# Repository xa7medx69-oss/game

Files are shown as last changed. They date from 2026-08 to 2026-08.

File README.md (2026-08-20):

# Physical Social Games

A reusable set of wearable ESP32-C3 game controls, a local hub, and a library of physical social games.

## Repository structure

| Folder | Contents |
|---|---|
| [`presentations/`](presentations/) | English and Arabic PowerPoint explainers |
| [`manuals/`](manuals/) | The 24 source manuals, compiled handbook, and expansion pack |
| [`hardware/`](hardware/) | PCB and enclosure design files |
| [`firmware/`](firmware/) | Wearable-node and hub firmware |
| [`software/`](software/) | Host web app, backend, and shared game logic |
| [`assets/`](assets/) | Images used by the manuals and presentations |
| [`tools/`](tools/) | Scripts that build, export, and verify project documents |

## Current status

The repository currently contains the complete product documentation, visual assets, compiled manuals, and game presentations. The PCB, enclosure, firmware, and host-application folders are ready for implementation files as development begins.

## Start here

1. Read the [product specification](manuals/chapters/01-product-specification.md).
2. Review the [hardware architecture](manuals/chapters/02-hardware-architecture.md) and [circuit design](manuals/chapters/03-circuit-design.md).
3. Use the [component list and BOM](manuals/chapters/04-component-list-and-bom.md) for the first prototype.
4. Follow the [firmware manual](manuals/chapters/06-firmware-manual.md) and [testing plan](manuals/chapters/14-testing-and-quality-plan.md).

See the [manual index](manuals/README.md) for the complete roadmap.

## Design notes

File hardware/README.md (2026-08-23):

# Hardware

Product hardware files belong here.

- [`pcb/`](pcb/) — schematics, PCB layouts, Gerbers, drill files, BOMs, and pick-and-place files.
- [`enclosure/`](enclosure/) — CAD, STL/STEP files, drawings, and assembly notes.
- [`3d-print/`](3d-print/) — print-ready prototype models, parametric generators, and build instructions.

The current design guidance is documented in manuals 02–05 and 12–15 under [`manuals/chapters`](../manuals/chapters/).

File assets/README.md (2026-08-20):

# Assets

- `games/` — illustrations and prompts for the 16-game PowerPoint decks.
- `handbook/` — diagrams and concept images used by the main handbook.
- `expansion-pack/` — illustrations for the eight-game expansion document.

Keep generated presentations and manuals out of this folder; their final files belong in `presentations/` and `manuals/compiled/`.

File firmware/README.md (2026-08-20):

# Firmware

ESP32-C3 product firmware belongs here.

Recommended layout:

- `wearable-node/` — button input, feedback, battery monitoring, and ESP-NOW communication.
- `hub/` — device pairing, event validation, game state, Wi-Fi, and WebSocket communication.
- `shared/` — shared packet definitions, IDs, constants, and tests.

Implementation requirements are in [Manual 06](../manuals/chapters/06-firmware-manual.md).

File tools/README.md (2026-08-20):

# Project Tools

- `presentations/` — builds the English and Arabic PowerPoint decks.
- `manuals/` — builds the Word manuals and exports PDFs.
- `quality/` — creates contact sheets for visual document review.

All scripts resolve paths from the repository root and no longer depend on a specific user's home directory.

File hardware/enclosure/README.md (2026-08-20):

# Enclosure Files

Place editable CAD files, printable STL files, STEP exports, drawings, and assembly notes here.

See [Manual 13](../../manuals/chapters/13-3d-printable-enclosure-instructions.md) for the current enclosure requirements.

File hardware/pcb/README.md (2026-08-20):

# PCB Files

Place the editable KiCad project here when circuit implementation begins.

Recommended layout:

- `wearable-node/` — wearable ESP32-C3 controller board.
- `hub/` — central ESP32-C3 hub board.
- `manufacturing/` — Gerbers, drill files, BOM, and pick-and-place exports.

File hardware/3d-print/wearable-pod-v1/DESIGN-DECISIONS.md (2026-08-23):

# Design Decisions

## Opening and closing method

The selected method is four metal M2 heat-set inserts in the base, four reusable screws through the lid, a radial tongue-and-groove alignment joint, and a separate TPU compression gasket.

| Method considered | Decision |
|---|---|
| Heat-set inserts and screws | Selected: repeatable servicing, controlled clamp force, replaceable gasket, and visible failure inspection |
| Screws directly into printed plastic | Rejected for regular servicing because threads wear and strip |
| Permanent snap fits | Rejected for the alpha because printer variation, fatigue, and hidden cracking make repeated battery access unreliable |
| Quarter-turn bayonet lid | Rejected for the wearable alpha because accidental rotation and uneven gasket compression require more physical validation |
| Adhesive or ultrasonic welding | Rejected because the battery and prototype electronics must remain serviceable |
| Magnets | Rejected because they do not provide controlled sealing force and are undesirable for a wearable attachment system |

## Button retention

The cap is installed from below the lid and has a larger underside flange. It therefore cannot leave the enclosure during play. Removing the four lid screws provides deliberate service access. A separate TPU diaphragm centers the press, limits dust entry, and transfers force to the switch.

## Attachment

The wearable interface is a separate screw-mounted plate rather than a clip molded into the electronics shell. Strap and clip experiments can therefore change without reprinting the sealed enclosure. The first build uses a wide fabric strap with a breakaway overlap; it avoids neck mounting and sharp metal against the body.

## Electronics layout

The battery and XIAO board sit side-by-side on a removable carrier. This avoids stacking the PCB directly over the pouch cell, improves inspection, and gives wires defined routes. The USB connector points toward the side opening. The external antenna must be routed separately after worn-position RF testing.

## Drop and sealing strategy

The TPU lower bumper is sacrificial and replaceable. The perimeter gasket and button diaphragm reduce dust/splash paths, but they do not create a certified ingress rating. A production seal needs material, compression, sweat, temperature-cycle, and laboratory ingress validation.

## Production path

This geometry is optimized for FDM prototype learning. After electronics, human-factors, and play testing stabilize, redesign it for injection molding with appropriate draft, ribs, uniform wall thickness, molded gasket features, and formal DFM review. Do not send this FDM model directly to tooling.

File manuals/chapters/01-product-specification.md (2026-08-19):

> Physical Social Games Business | Manual 01 | Version 0.1 | 2026-08-19

# Product Specification

## Purpose
Define the product to build, who it is for, what the MVP must prove, and what is deliberately postponed.

## Product promise
A reusable box of six wearable electronic controls and one hub that turns a room, garden, majlis, or event space into a library of original real-life games. The physical devices capture deliberate presses; the digital host controls rules, timing, teams, feedback, scoring, and replay.

**MVP decision:** build six wearable nodes plus one hub. The first release is a supervised prototype for adults and older teens, not a children's toy and not a finished waterproof consumer product.

## Flagship game: Pulse Hunt
**Objective:** survive until time expires, or as the Hunter eliminate all Runners.

**Players:** 4-6. One Hunter; 3-5 Runners. For three players, use one Hunter and two Runners with a shorter arena.

**Setup:** charge and assign one pod per player; clip pods high on the upper back; mark a clear play boundary; remove trip hazards; select 5-8 minutes; give Runners a 20-second head start; test every pod before starting.

**Core rules:** the Hunter eliminates a Runner by pressing the Runner's pod once until it confirms with light, vibration, and a sound from the host. Only the device may be touched. No grabbing, blocking doorways, tackling, pushing, hiding in locked rooms, stairs, roads, pools, kitchens, or vehicle areas. Eliminated players freeze, raise a hand, and walk to the safe zone.

**False-press protection:** a valid press is 80-900 ms, followed by a one-second lockout. The hub acknowledges the event. The node changes to red only after acknowledgement; if acknowledgement fails, it vibrates twice and retries.

**Winning:** Runners win if at least one remains alive at zero. The Hunter wins if all are eliminated. Tie-break: fastest complete elimination time.

**Variations:** two Hunters; team rescue with a 3-second teammate hold; three-life mode; shrinking arena announced by the host; silent mode using vibration only; score attack where each confirmed tag is one point and eliminated players re-enter after 20 seconds.

## Seven additional original games

| Game | Core idea | Button use |
|---|---|---|
| Vault Heist | Players steal digital gems while protecting their own vault. | Hold an opponent's pod for 1.5 seconds; a successful steal triggers a cooldown shield. |
| Signal Chain | Cooperative memory and movement challenge. | LEDs cue a changing player sequence; players press their own pods in order before time runs out. |
| Guardian Link | Secret pairs protect one another while completing public tasks. | A partner can cancel one hit by pressing the threatened player's pod within three seconds. |
| Territory Pulse | Teams control physical zones made from detached pods. | Hold a zone pod until its LED changes to the team's color; control scores over time. |
| Echo Match | Fast reaction and pattern recognition. | Players copy color/sound patterns on their own pods; fastest accurate response scores. |
| Silent Mission | Hidden individual objectives inside a normal gathering. | Short and long presses log secret actions; the host reveals completed missions at the end. |
| Relay Rush | Cooperative race against a dynamic route. | The host lights the next player's pod; correct presses pass the signal, mistakes add time. |

## Target user and occasion
Primary: UAE families and friend groups aged 14+, playing at villas, ghabgas, majlis-adjacent spaces, parks, and private gatherings. Secondary: birthdays, youth groups, hospitality venues, and later corporate events. The host should understand setup within three minutes and start a game within five.

## MVP acceptance criteria
- Six nodes connect through one hub without manual repair during a 30-minute session.
- A physical press appears in the UI within 200 ms at 95th percentile in the intended arena.
- At least 99.5% of deliberate valid presses are registered in a 1,000-press bench test.
- No duplicate scoring from one press; every event has a sequence number and acknowledgement.
- A new host can set up Pulse Hunt using only the quick-start page.
- In three playtests, at least 70% of participants request another round and rate fun at 4/5 or higher.

## Not in MVP
Native iOS/Android apps, cloud accounts, children under 14, public matchmaking, GPS, microphones, cameras, precise location tracking, custom injection-moulded tooling, certified waterproofing, and mass-production charging cases.

## Product risks and response
**Accidental activation:** use force/travel tuning, press windows, lockouts, hub acknowledgement, and playtesting. **Unsafe chasing:** strict arena rules, age gate, host briefing, and game modes that do not require running. **Wireless dropouts:** local star topology, retries, health beacons, and no cloud dependency. **One-game novelty:** ship only after three mechanics test well, then expand the library through software.

## Build instruction
Freeze this MVP specification for the first prototype sprint. New ideas go into a backlog unless they affect safety, event reliability, or the fun hypothesis.

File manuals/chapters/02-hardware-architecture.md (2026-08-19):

> Physical Social Games Business | Manual 02 | Version 0.1 | 2026-08-19

# Hardware Architecture

## Recommended MVP architecture
Use **six Seeed XIAO ESP32-C3 wearable nodes plus one XIAO ESP32-C3 hub**. Nodes send compact events to the hub over ESP-NOW. The hub runs a local Wi-Fi access point and WebSocket server; a phone or laptop joins the hub network and opens the local web interface. Internet is optional.

```text
[6 wearable nodes] -- ESP-NOW --> [hub] -- local Wi-Fi/WebSocket --> [phone/laptop browser]
```

This is better for the proof-of-concept than connecting six BLE peripherals directly to a phone: the host pairs once with the hub, the game works offline, event timing is centralized, and browser/device Bluetooth differences are removed. ESP32-C3 supports 2.4 GHz Wi-Fi and Bluetooth LE 5, so the same dev board preserves experimentation options. Official overview: https://docs.espressif.com/projects/esp-hardware-design-guidelines/en/latest/esp32c3/product-overview.html

## Node blocks
- XIAO ESP32-C3 module with antenna kept clear of battery and metal clip.
- Large momentary switch under a soft press cap.
- Addressable RGB LED or a 6-8 LED ring for player/status feedback.
- Coin vibration motor driven through a MOSFET.
- Optional piezo buzzer; keep node audio subtle and let the host produce most sound.
- 500 mAh protected LiPo, slide power switch, and USB-C charging through the board.
- Prototype enclosure with breakaway fabric strap or rounded clip.

## Hub blocks
- XIAO ESP32-C3 connected to USB power.
- ESP-NOW receiver and event authority.
- Local Wi-Fi access point, HTTP server, and WebSocket endpoint.
- USB serial debug channel; optional OLED only for diagnostics.

## Protocol
Each node sends `device_id`, `event_type`, `sequence`, `node_time_ms`, battery percentage, and a message authentication/check value. The hub deduplicates by device plus sequence, timestamps receipt, applies the game rule, and replies with an acknowledgement containing the accepted state. Retry at 40, 100, and 220 ms with random jitter, then show a local error pattern.

## Range target
Design for 25 m reliable line-of-sight and 10-15 m through typical villa partitions. Do not market a range until measured. Test the exact antenna orientation with the pod worn against different fabrics and body positions because the human body attenuates 2.4 GHz.

## Consumer architecture after validation
Re-evaluate a Nordic nRF52-class design for lower power and a robust proprietary 2.4 GHz/BLE hub. The nRF52840 supports Bluetooth LE, Bluetooth Mesh, NFC, Thread, and Zigbee, but it raises firmware/tooling and unit-cost complexity. Official product page: https://www.nordicsemi.com/products/nrf52840

## Battery and thermal targets
Active play: 8 hours minimum; shelf-off leakage: under 5% per month; charge time under 2.5 hours; protected cell; enclosure surface below 42 C in normal use. For the MVP, measure actual current in idle, active radio, LED animation, vibration, and power-off states before claiming runtime.

## Reliability rules
- The hub, not the node, owns the official game state.
- Never award points from an unacknowledged local press.
- Every node emits a health beacon every two seconds during a game.
- The UI warns at low battery, weak signal, or missed beacons.
- A reconnecting node requests current state before accepting gameplay input.

## Decision gate
Keep ESP-NOW through the first three playtest rounds. Change radio architecture only if measured packet loss, range, power, platform compatibility, or certification economics fail the targets.

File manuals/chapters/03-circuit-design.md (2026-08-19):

> Physical Social Games Business | Manual 03 | Version 0.1 | 2026-08-19

# Circuit Design

## Prototype node wiring

| Function | XIAO ESP32-C3 pin | Circuit instruction |
|---|---|---|
| Main press | D1 / GPIO3 | Switch to GND; enable internal pull-up; add 100 nF only if software debounce is insufficient. |
| RGB LED | D2 / GPIO4 | WS2812 data through 330 ohm series resistor; 100 uF across LED supply; limit brightness in firmware. |
| Buzzer | D3 / GPIO5 | Drive piezo or magnetic buzzer through an NPN transistor and base resistor; add flyback protection if inductive. |
| Vibration | D4 / GPIO6 | Logic-level N-MOSFET low-side drive; flyback diode across coin motor; 100 nF motor suppression. |
| Battery sense | D0 / GPIO2 | 220 k/100 k divider to ADC; enable through a transistor if idle leakage matters. |
| Power | BAT and GND | Protected 3.7 V LiPo to battery pads; physical slide switch in series for a true off state. |

## Electrical rules
Keep the 2.4 GHz antenna edge free of copper, battery, motor, steel clip, and fingers. Place motor and buzzer away from the antenna. Add test pads for 3V3, GND, button, LED data, UART TX/RX, and battery. Use keyed battery connectors and strain relief. Do not charge unattended during early prototypes.

## Switch and press design
The large visible cap should transfer force to a small rated tactile switch without side-loading it. Start with 1.5-2.5 N actuation and 0.5-1.0 mm perceived travel. The enclosure must prevent clothing pressure from maintaining the switch. A raised protective rim helps but must not make intentional presses difficult.

## Protection for a production PCB
Include reverse-polarity protection, LiPo over-charge/over-discharge/short protection, USB ESD protection, motor transient suppression, programming pads, a reset method, and a current-measurement link. Use only a certified battery pack and document cell traceability.

## Verification instruction
Before connecting a battery, perform continuity and resistance checks. Power from a current-limited bench supply at 3.8 V with a 150 mA limit, confirm quiescent current, then test each output separately. Record peak current during LED white, motor start, radio transmit, and combined worst case.

## Production handoff outputs
Schematic PDF, ERC-clean source, PCB layout, Gerbers, drill files, pick-and-place, BOM with manufacturer part numbers and alternates, test-point map, programming fixture drawing, and a written bring-up procedure.

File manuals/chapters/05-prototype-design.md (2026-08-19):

> Physical Social Games Business | Manual 05 | Version 0.1 | 2026-08-19

# Prototype Design

## Prototype stages
**P0 - one-button proof:** one node, one hub, one browser. Demonstrate press, acknowledgement, UI state, and reconnect.

**P1 - six wired-on-bench nodes:** six powered nodes on a table. Run 1,000 scripted/manual presses, duplicates, simultaneous events, resets, and low-signal tests.

**P2 - wearable alpha:** battery power, 3D-printed housings, straps/clips, LED and vibration. Conduct controlled walking-speed games.

**P3 - playtest kit:** refined enclosures, labelled IDs, carry tray, charging checklist, host guide, and three complete game modes.

## Enclosure target
Prototype diameter 58-65 mm; depth 20-28 mm; mass below 70 g; 45-50 mm press area; minimum 2 mm rounded shell walls; no sharp external corners; recessed power switch; USB-C access that cannot be hit during play. Use a replaceable fabric/clip interface so the electronics do not need redesign when wear testing changes.

## Attachment
Start with a wide hook-and-loop armband/back strap plus a rounded clip adapter. Avoid strong magnets near medical devices and avoid lanyards or neck mounting. A production attachment should release under abnormal load and must not use a sharp metal edge against the body.

## Build order
1. Flash unique IDs and radio keys onto all boards.
2. Assemble hub and verify all six nodes on USB power.
3. Add one battery-powered node and measure current/temperature.
4. Clone the validated wiring to the other five.
5. Print one enclosure, conduct fit/press/antenna checks, then print the set.
6. Run bench reliability before any active play.
7. Run a safety briefing and low-speed playtest before chase variants.

## Exit criteria
Six nodes run 30 minutes without a reset, every node reconnects within five seconds after power cycling, the host sees battery/signal status, and two unfamiliar hosts can set up using the quick-start instructions.

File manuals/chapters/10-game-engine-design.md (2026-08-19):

> Physical Social Games Business | Manual 10 | Version 0.1 | 2026-08-19

# Game Engine Design

## Principle
Hardware emits simple physical facts; game definitions decide meaning. A `PRESS` must not be hard-coded as elimination because the same input may steal points, capture a zone, confirm a sequence, rescue a teammate, or complete a mission.

## Engine components
Game manifest; configuration schema; player/team allocator; deterministic reducer; timers; random seed service; rule validators; effect dispatcher; score/winner evaluator; pause/recovery; replay log.

## Normalized inputs
`PRESS`, `HOLD_STARTED`, `HOLD_COMPLETED`, `RELEASE`, `DEVICE_ONLINE`, `DEVICE_OFFLINE`, `BATTERY_LOW`, and host commands. The engine accepts only validated inputs from known devices in the current session.

## Game definition contract
Each game declares player range, age guidance, space and activity level, setup, allowed roles, defaults, event handlers, state shape, feedback effects, winner conditions, timeouts, reconnection policy, safety warning, and analytics events.

## Determinism
Store the random seed at session creation. Timers are derived from the hub monotonic clock. Every state change emits an immutable domain event. This makes bugs reproducible and supports match replay without video or personal tracking.

## New-game checklist
Write a one-sentence fun promise; define player choices; identify the physical action; cap downtime; add a comeback path; specify ambiguous simultaneous events; define disconnection behavior; run a paper prototype; then implement. Reject games whose novelty depends only on changing colors or scores.

## Portfolio balance
Launch library target: one chase game, one team strategy game, one cooperative memory game, one low-mobility social/hidden-mission game, and one reaction game. This makes the kit useful across villas, indoor gatherings, mixed mobility, and short/long sessions.

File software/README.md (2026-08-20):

# Software

Host-side product code belongs here.

Recommended layout:

- `web-app/` — local browser interface served by the hub.
- `game-engine/` — reusable game rules and state machines.
- `backend/` — optional online services added after the offline MVP.
- `shared/` — schemas, types, and shared utilities.

See manuals 07–11 under [`manuals/chapters`](../manuals/chapters/).

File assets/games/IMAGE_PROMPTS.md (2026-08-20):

# Image prompt set

Mode: OpenAI built-in image generator.

Hardware/style reference: `assets/handbook/kit-concept.png`.

## Shared direction

Each game used the following shared production direction, combined with its scene brief below:

```text
Use case: illustration-story
Asset type: 16:9 PowerPoint game explainer illustration
Audience: understandable at a glance by a 10-year-old
Input image: the kit concept is a hardware and palette reference for round electronic pods; preserve navy shells and teal, coral, amber, and warm-white lights
Style/medium: polished friendly 3D children's educational illustration, rounded forms, expressive poses, clean modern composition
Color palette: deep navy, teal, coral, amber, warm off-white
Constraints: no written words, no numbers, no logos, no watermark; show safe device use; avoid grabbing, pushing, tackling, dangerous obstacles, or threatening behavior
```

## Selected scene briefs

1. **Pulse Hunt** — Bright garden with a glowing safe boundary. Exactly five players: one Hunter presses only a Runner's upper-back pod, two Runners move safely, and one tagged player raises a hand and walks to a teal safe zone.
2. **Vault Heist** — Two glowing team vault circles. A player safely holds an opponent's arm pod, a gem-shaped light moves between vaults, and a shield ring appears after the steal.
3. **Signal Chain** — Six players in a semicircle. Their pods light in a visible sequence connected by arrows; the first player presses their own pod while the others remember the next turn.
4. **Guardian Link** — Secret pairs are suggested by matching heart-light links. A partner presses the threatened player's pod in time, creating a protective shield that cancels a hit.
5. **Territory Pulse** — Three safe floor zones with detached pods on stable bases. Two teams walk between zones while teal and coral lights show which team controls each area.
6. **Echo Match** — Six players around a central hub that shows a simple three-color pattern. Players copy the pattern on their own pods; a star glow marks the first correct answer.
7. **Silent Mission** — Six players at a friendly gathering, each with one harmless mission symbol in a thought bubble. A central player quietly presses their own wrist pod; a table hub shows completed stars.
8. **Relay Rush** — Six players arranged along a curved route. A glowing signal travels through arrows from one lit pod to the next; a clock icon shows that mistakes add time.
9. **Crown Circuit** — Three-beat visual story: an amber crown marks the holder, a challenger presses the Crown pod, then the two duelists press their own pods after a flash while other pods lock.
10. **Courier Code** — Exactly five seated players. A glowing envelope moves during a secret handoff, the Interceptor safely scans a different pod and gets a miss, and another player performs a decoy.
11. **Double Lock** — Stable table pods and a visual color clue. Two players hold the matching pods simultaneously as progress bars meet and a large lock opens.
12. **Market Rush** — Six seated players trade fictional Spark, Fabric, and Time icons. Two players confirm together, resources swap, and a completed icon-only contract creates a Reputation star.
13. **Power Grid** — Six pods form a generator ring around a glowing miniature city. Players raise output, cool a hot pod, and link two pods for a repair while supply and demand bars match.
14. **Rhythm Rivals** — Six players follow colored beat waves from a central hub. Pods glow before each cue; two players hit a shared team note and earn a perfect-timing star.
15. **Switchback** — Six seated players form a circle. A white Signal sits on the active pod while arrows show short, long, and double-press routes; a reverse icon flips the directions.
16. **Ghost Frequency** — Six players conduct a pair test. The hub returns a green same-result, an icon-only evidence graph connects colored dots, and the hidden Drifter has a small playful static swirl.

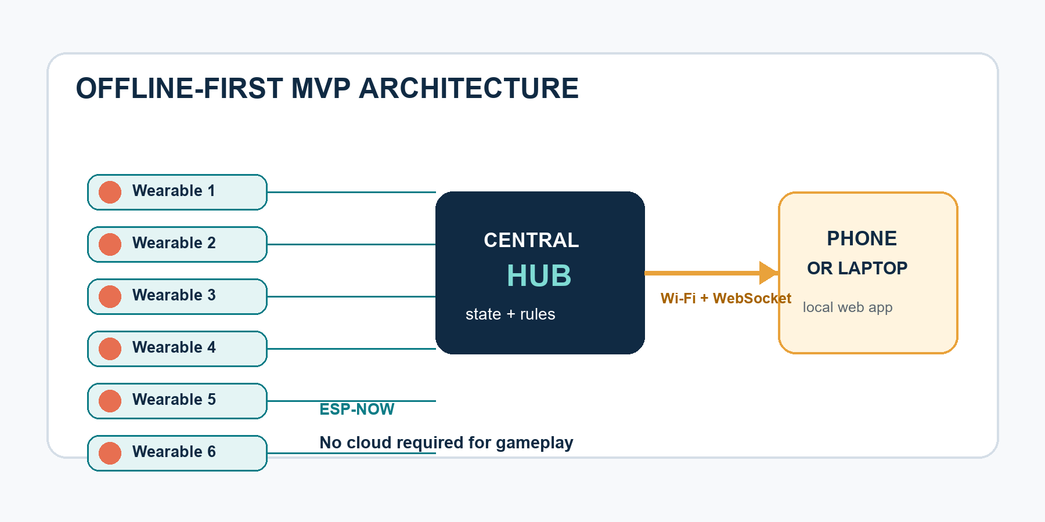
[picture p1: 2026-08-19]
assets/handbook/architecture.png

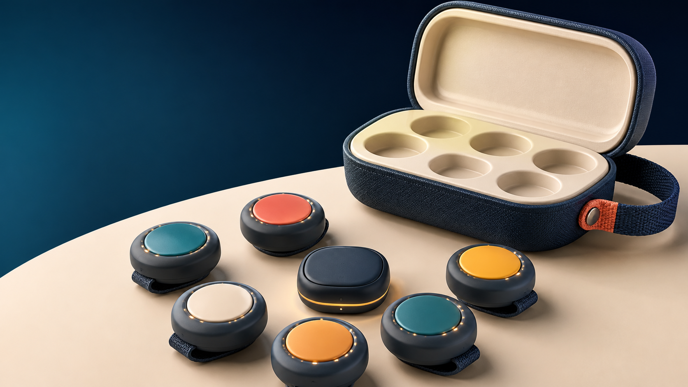
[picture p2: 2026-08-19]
assets/handbook/kit-concept.png

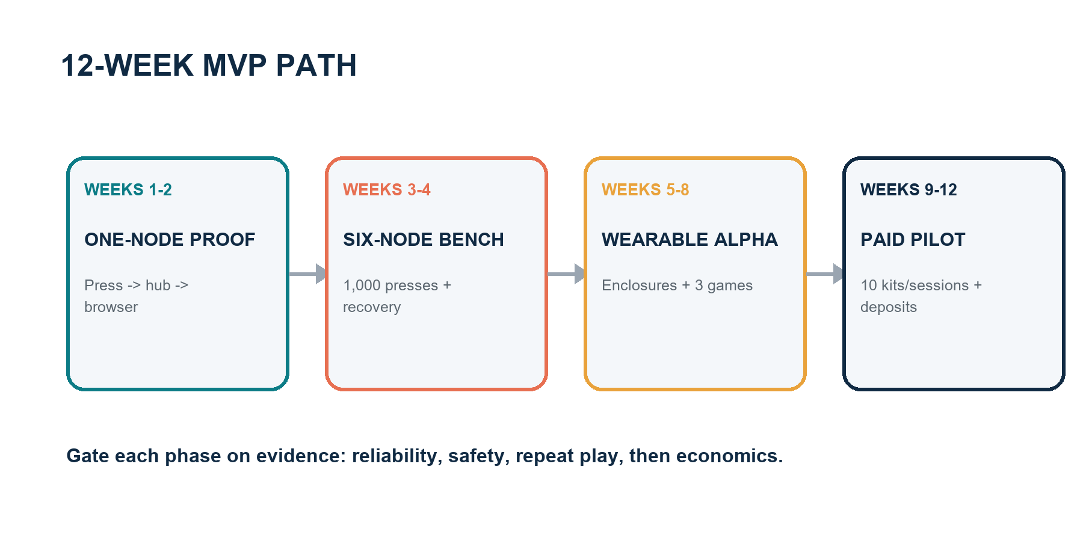
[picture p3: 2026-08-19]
assets/handbook/roadmap.png

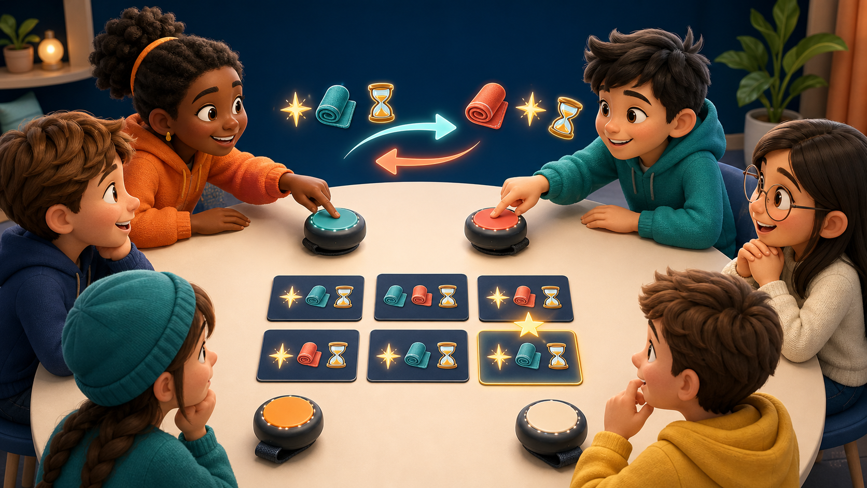
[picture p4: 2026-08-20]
assets/games/12-market-rush.png

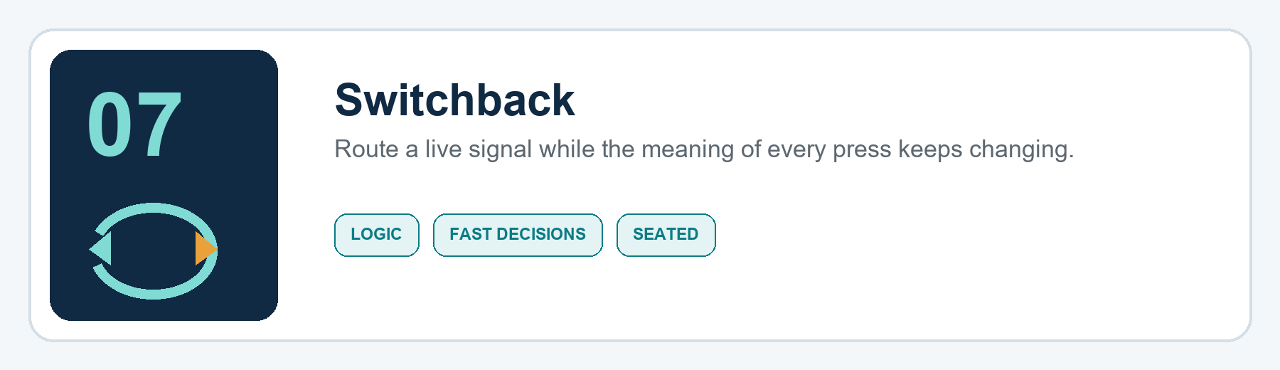
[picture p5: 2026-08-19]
assets/expansion-pack/game-07.png

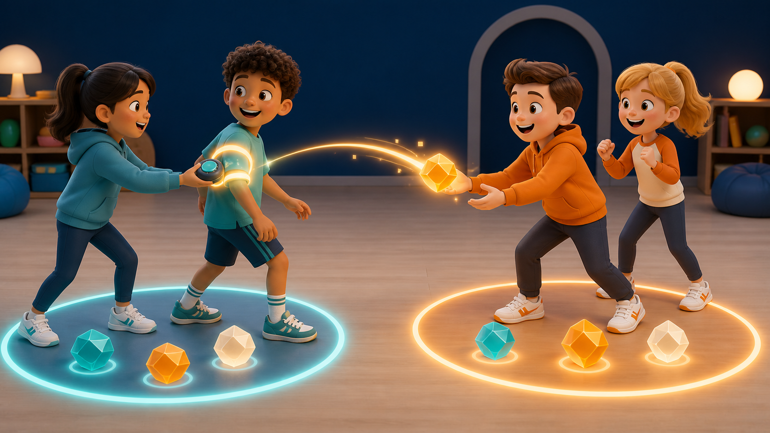
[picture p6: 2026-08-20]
assets/games/02-vault-heist.png

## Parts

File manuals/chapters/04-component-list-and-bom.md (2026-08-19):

> Physical Social Games Business | Manual 04 | Version 0.1 | 2026-08-19

# Component List and BOM

## Buy list for one seven-board MVP

| Item | Qty | Planning cost (AED) | Notes |
|---|---:|---:|---|
| Seeed XIAO ESP32-C3 | 7 | 210-315 | Six nodes plus one hub; buy one spare if budget allows. |
| Protected 500 mAh LiPo | 6 | 90-150 | Use reputable packs with correct polarity and connectors. |
| Large momentary switches/caps | 8 | 35-80 | Six plus spares; prototype arcade or low-profile caps. |
| RGB LEDs/rings | 8 | 40-90 | One per node plus spares. |
| Coin vibration motors | 8 | 40-80 | Optional in prototype round one but recommended. |
| Buzzers, MOSFETs, diodes, passives | 1 lot | 35-70 | Breadboard/protoboard stage. |
| Power switches and wire/connectors | 1 lot | 30-60 | Add strain relief and insulation. |
| USB-C charging cable set/charger | 1 | 45-90 | Multi-port quality charger; never use damaged cells. |
| Prototype enclosures/straps/clips | 6 | 90-180 | 3D printing, hook-and-loop, fabric straps. |
| Hub case and optional OLED | 1 | 35-75 | OLED is diagnostic, not required. |

**Expected prototype total:** approximately AED 615-1,190 before tools, shipping, and failed parts. This is a planning range, not a supplier quote.

## Required tools
Temperature-controlled soldering iron, lead-free or appropriately handled solder, flux, flush cutters, wire stripper, heat-shrink, multimeter, USB power meter, bench supply with current limit, small scale/calipers, and access to a 3D printer. A basic logic analyser is useful for debugging.

## Supplier discipline
Record supplier, order date, exact MPN, lot/batch, price, lead time, datasheet URL, and substitute. Do not silently swap batteries, radios, switches, or plastics. For each critical part maintain one approved alternate and document the validation needed after substitution.

## Cost-down ladder
Prototype dev boards first; then one custom PCB; then panelized PCBs and a simple machined/printed enclosure; only after demand validation consider injection moulding and a charging case. Do not spend on tooling before event reliability and repeat-play are proven.

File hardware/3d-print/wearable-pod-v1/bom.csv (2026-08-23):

category | item | quantity | material_or_specification | notes
printed | Base shell | 1 | PETG | Contains inserts and electronics
printed | Top lid | 1 | PETG | Four-screw service closure
printed | Button cap | 1 | PETG | 47.4 mm press face
printed | Button membrane | 1 | TPU 95A | Flip after printing so plunger points down
printed | Perimeter gasket | 1 | TPU 95A | Replace if permanently compressed or damaged
printed | Light ring | 1 | Natural or translucent PETG | Optical performance requires LED testing
printed | Drop bumper | 1 | TPU 95A | Stretch-on replaceable impact part
printed | Strap mount | 1 | PETG | Two 29 x 5 mm strap slots
printed | Electronics carrier | 1 | PETG | Measure battery before use
fastener | M2 button-head screw | 4 | M2 x 6 mm | Hand tighten in cross pattern
fastener | M2 heat-set insert | 4 | Approx. 3.2 mm OD x 3 mm | Select pilot using coupon
fastener | M2.5 low-profile screw | 2 | M2.5 x 6 mm | Strap plate attachment
fastener | M2.5 heat-set insert | 2 | Approx. 3.7 mm OD | Blind underside bosses
fastener | M2 thread-forming screw | 2 | Length selected after physical stack measurement | Electronics carrier
soft_good | Wearable strap | 1 | 25 mm soft hook-and-loop | Breakaway overlap required
soft_good | Battery retaining strap | 1 | 8 mm fabric or hook-and-loop | No rigid clamp across pouch cell
soft_good | Wearer pad | 1 | Thin closed-cell foam | Replaceable and cleanable
electronics | Controller board | 1 | Seeed XIAO ESP32-C3 21 x 17.8 mm | Verify assembled height and antenna lead
electronics | Battery | 1 | Protected LiPo maximum modeled envelope 31 x 21.5 x 6.5 mm | Exact qualified pack required
electronics | Tactile switch and actuator | 1 | 1.5-2.5 N target | Physical height controls button travel

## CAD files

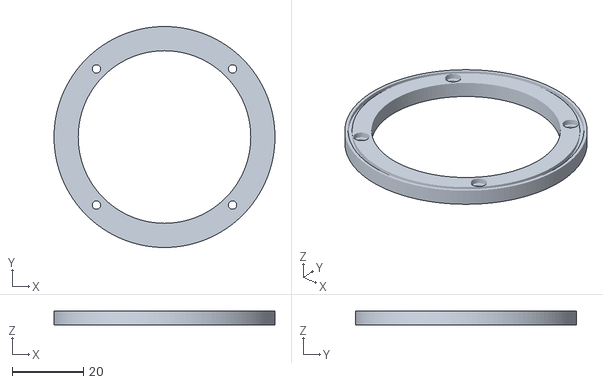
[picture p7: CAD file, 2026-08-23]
hardware/3d-print/wearable-pod-v1/stl/02-top-lid.stl
62.0 x 62.0 x 4.00

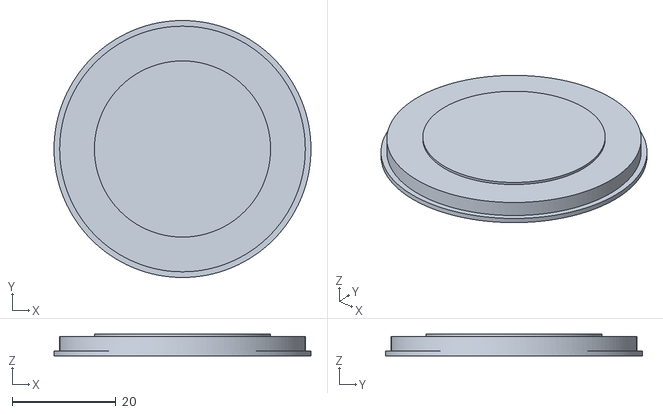
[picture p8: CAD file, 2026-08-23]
hardware/3d-print/wearable-pod-v1/stl/03-button-cap.stl
49.6 x 49.6 x 4.15

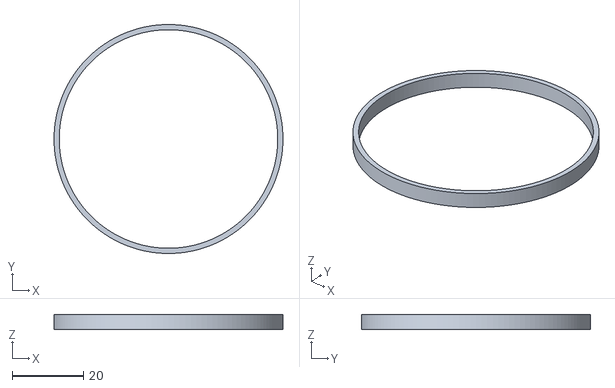
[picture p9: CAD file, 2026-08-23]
hardware/3d-print/wearable-pod-v1/stl/07-drop-bumper-tpu.stl
64.4 x 64.4 x 4.20

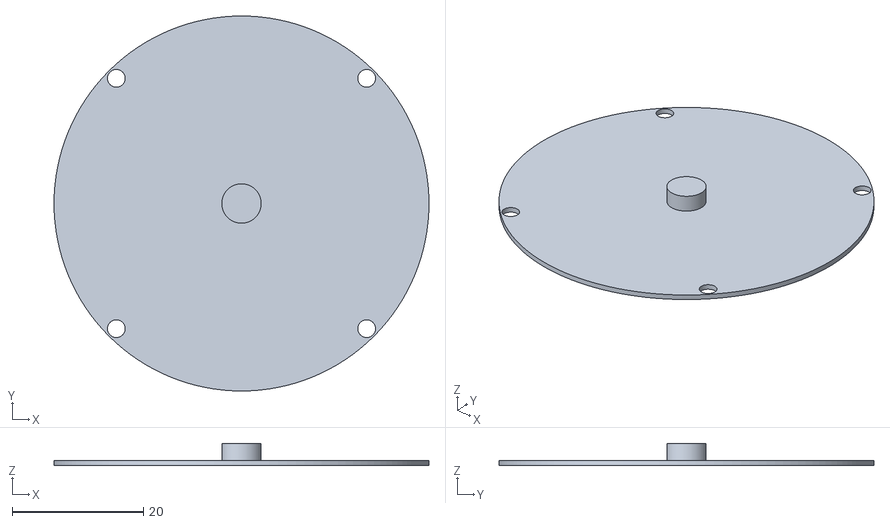
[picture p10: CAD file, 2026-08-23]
hardware/3d-print/wearable-pod-v1/stl/04-button-membrane-tpu.stl
57.2 x 57.2 x 3.40

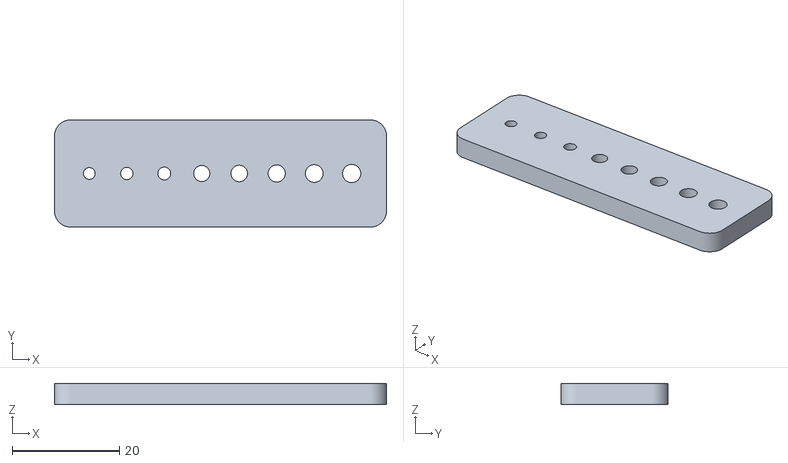
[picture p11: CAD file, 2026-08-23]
hardware/3d-print/wearable-pod-v1/stl/10-tolerance-coupon.stl
62.0 x 20.0 x 4.00

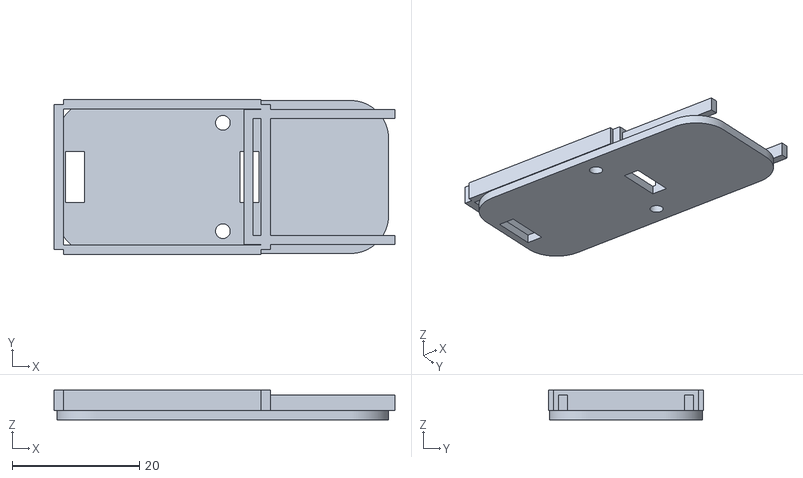
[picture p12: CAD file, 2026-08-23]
hardware/3d-print/wearable-pod-v1/stl/09-electronics-carrier.stl
53.5 x 24.3 x 4.70

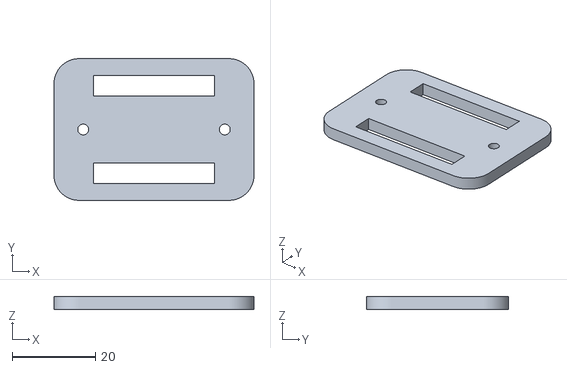
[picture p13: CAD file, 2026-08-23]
hardware/3d-print/wearable-pod-v1/stl/08-strap-mount.stl
48.0 x 34.0 x 3.00

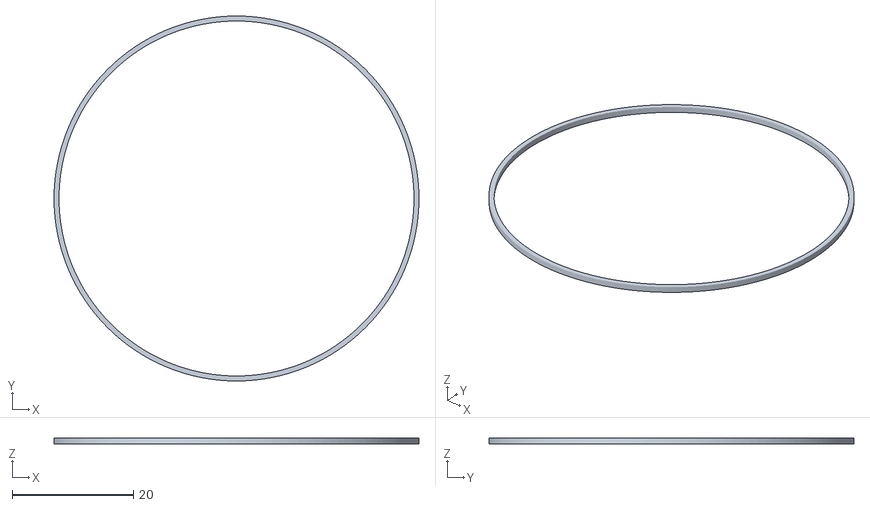
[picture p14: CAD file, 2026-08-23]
hardware/3d-print/wearable-pod-v1/stl/06-light-ring-transparent.stl
60.2 x 60.2 x 1.00

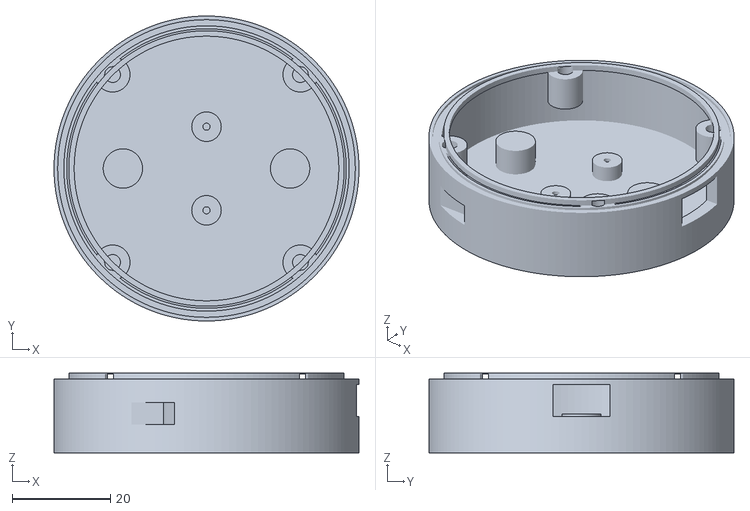
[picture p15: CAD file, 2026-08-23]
hardware/3d-print/wearable-pod-v1/stl/01-base-shell.stl
62.0 x 62.0 x 16.2

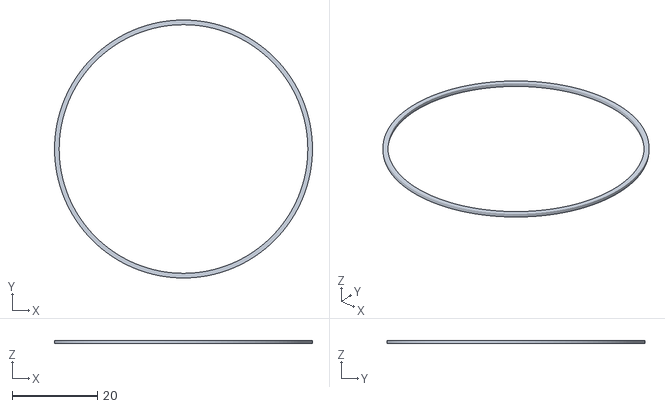
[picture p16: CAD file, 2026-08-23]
hardware/3d-print/wearable-pod-v1/stl/05-perimeter-gasket-tpu.stl
60.4 x 60.4 x 0.8

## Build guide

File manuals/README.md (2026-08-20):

# Physical Social Games Business - Manual Index

A practical, original, UAE-ready roadmap from playable prototype to launch

## Files

01. [Product Specification](chapters/01-product-specification.md)
02. [Hardware Architecture](chapters/02-hardware-architecture.md)
03. [Circuit Design](chapters/03-circuit-design.md)
04. [Component List and BOM](chapters/04-component-list-and-bom.md)
05. [Prototype Design](chapters/05-prototype-design.md)
06. [Firmware Manual](chapters/06-firmware-manual.md)
07. [Website and Host App](chapters/07-website-and-host-app.md)
08. [Backend and API](chapters/08-backend-and-api.md)
09. [Database and Data Model](chapters/09-database-and-data-model.md)
10. [Game Engine Design](chapters/10-game-engine-design.md)
11. [UI and UX Manual](chapters/11-ui-and-ux-manual.md)
12. [Industrial Design Manual](chapters/12-industrial-design-manual.md)
13. [3D-Printable Enclosure Instructions](chapters/13-3d-printable-enclosure-instructions.md)
14. [Testing and Quality Plan](chapters/14-testing-and-quality-plan.md)
15. [Manufacturing Plan](chapters/15-manufacturing-plan.md)
16. [Packaging and Quick-Start](chapters/16-packaging-and-quick-start.md)
17. [Branding Manual](chapters/17-branding-manual.md)
18. [Pricing Manual](chapters/18-pricing-manual.md)
19. [Business Model Manual](chapters/19-business-model-manual.md)
20. [Marketing Manual](chapters/20-marketing-manual.md)
21. [Launch Strategy](chapters/21-launch-strategy.md)
22. [UAE Business and Compliance](chapters/22-uae-business-and-compliance.md)
23. [Legal and IP Manual](chapters/23-legal-and-ip-manual.md)
24. [Future Expansion Roadmap](chapters/24-future-expansion-roadmap.md)

## Compiled files

- [Business handbook (PDF)](compiled/Physical-Social-Games-Business-Handbook.pdf)
- [Business handbook (Word)](compiled/Physical-Social-Games-Business-Handbook.docx)
- [Separate manuals archive](compiled/Physical-Social-Games-Separate-Manuals.zip)
- [Eight-game expansion pack](expansion-pack/README.md)

## Start here

Read Manual 01, buy from Manual 04, follow Manual 05, implement Manual 06, and use Manual 14 before active playtests.

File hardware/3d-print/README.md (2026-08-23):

# 3D-Printable Hardware

## Current model

- [`wearable-pod-v1/`](wearable-pod-v1/) — serviceable 62 mm wearable game-button enclosure.

Every model folder should contain editable parametric source, print-ready STL files, a BOM, print settings, assembly instructions, validation notes, and a revision history.

These are prototype files. A successful slice or print does not prove electrical, battery, impact, skin-contact, ingress, or child-product safety.

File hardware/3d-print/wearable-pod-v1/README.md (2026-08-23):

# Wearable Pod V1

A serviceable, parametric enclosure for one wearable Physical Social Games button.

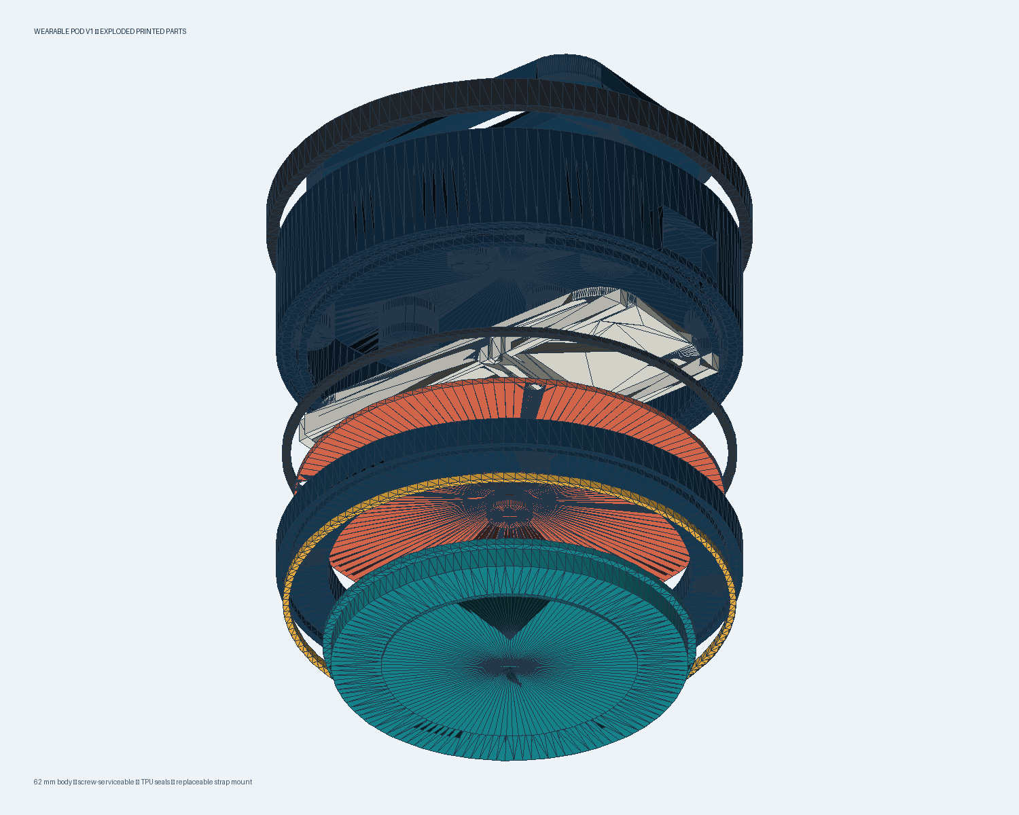
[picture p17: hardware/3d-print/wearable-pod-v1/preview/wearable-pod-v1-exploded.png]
Exploded enclosure preview


## Design summary

- 62 mm nominal body diameter.
- 47.4 mm obvious press surface with approximately 0.8 mm intended travel.
- Four M2 screws into heat-set inserts for repeatable opening and closing.
- Tongue-and-groove shell alignment plus a replaceable TPU compression gasket.
- Captured button cap: it cannot fall out while the enclosure is closed.
- Separate TPU diaphragm for dust resistance and compliant button return.
- Removable electronics carrier for a 21 × 17.8 mm XIAO ESP32-C3 and a battery up to 31 × 21.5 × 6.5 mm.
- Separate USB-C and recessed power-switch openings.
- Replaceable two-screw strap plate with two 29 × 5 mm strap slots.
- Stretch-on TPU drop bumper.
- No glue is required to service the enclosure.

## Files

- [`generate_models.py`](generate_models.py) — editable parametric source.
- [`model-validation.json`](model-validation.json) — recorded mesh and mechanical-clearance checks.
- [`stl/`](stl/) — ten generated and watertight print files.
- [`preview/wearable-pod-v1-exploded.glb`](preview/wearable-pod-v1-exploded.glb) — interactive exploded 3D model.
- [`preview/critical-dimensions.svg`](preview/critical-dimensions.svg) — first-build dimensional reference.
- [`PRINTING.md`](PRINTING.md) — material, orientation, slicing, and tolerance guidance.
- [`ASSEMBLY.md`](ASSEMBLY.md) — complete opening, closing, and assembly process.
- [`DESIGN-DECISIONS.md`](DESIGN-DECISIONS.md) — why this closure and attachment method were selected.
- [`bom.csv`](bom.csv) — printed and purchased parts.

## Important assumptions

The official XIAO ESP32-C3 board outline is 21 × 17.8 mm, but connected wires, the external antenna, battery connector, and solder joints also need clearance. The battery envelope in this model is only a starting maximum. Measure the exact purchased cell and all assembled electronics with calipers before printing six housings.

The enclosure is not certified waterproof and must not be described with an IP rating. The gasket and diaphragm are prototype dust/splash-control features that require physical testing.

Critical dimensions

## Regenerating the files

```powershell
python -m pip install -r requirements.txt
python generate_models.py
```

The generator rejects parts that are not watertight, have inconsistent triangle winding, or have non-positive volume.

## References

- [Official Seeed Studio XIAO ESP32-C3 dimensions and resources](https://wiki.seeedstudio.com/XIAO_ESP32C3_Getting_Started/)
- [Project enclosure requirements](../../../manuals/chapters/13-3d-printable-enclosure-instructions.md)
- [Project industrial-design requirements](../../../manuals/chapters/12-industrial-design-manual.md)

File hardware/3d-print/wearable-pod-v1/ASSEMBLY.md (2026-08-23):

# Assembly, Opening, and Closing

## Purchased hardware

- Four M2 × 6 mm button-head screws for the top lid.
- Four M2 heat-set inserts, approximately 3.2 mm outside diameter and 3 mm long, selected using the tolerance coupon.
- Two M2.5 × 6 mm low-profile screws for the strap plate.
- Two matching M2.5 heat-set inserts, approximately 3.7 mm outside diameter.
- Two M2 thread-forming screws for the removable electronics carrier.
- 25 mm wide soft hook-and-loop strap with a breakaway overlap.
- 8 mm removable battery-retaining strap.
- Thin closed-cell foam wearer pad and battery insulation.

Do not substitute fasteners until their head, length, thread engagement, and internal clearance have been checked in CAD and in a transparent or empty test assembly.

## Heat-set inserts

1. Print and test the tolerance coupon.
2. Support the boss from below on a flat surface.
3. Use a temperature-controlled insertion tip sized for the insert.
4. Press vertically without forcing or twisting the boss.
5. Stop when the insert is flush; do not push it into the battery cavity.
6. Let the plastic cool fully before inserting a screw.
7. Reject a boss that is cracked, distorted, loose, or visibly tilted.

Install four M2 inserts from the open top of the base. Install the two strap-mount inserts from the wearer-facing underside.

## Electronics carrier

1. Measure the finished battery. It must fit without bending, pinching, or compressing the pouch cell.
2. Add electrical insulation between the cell and every PCB/solder surface.
3. Place the battery in the left pocket and retain it with an 8 mm removable fabric strap through the two carrier slots. Do not use a rigid clamp across the cell.
4. Slide the XIAO board into the right-side rails with USB-C toward the side opening.
5. Route the external antenna away from the battery, vibration motor, metal screws, and the wearer’s body. Do not coil the antenna lead tightly.
6. Route wires with service loops and strain relief. No wire may cross a screw boss, shell tongue, gasket, button plunger, or sharp printed edge.
7. Attach the carrier using two M2 thread-forming screws. Tighten by hand only.

## Button and lid stack

1. Place the translucent light ring into the lid’s upper annular recess.
2. Insert the rigid button cap from the underside of the lid. Its larger flange must remain below the lid opening.
3. Flip the TPU membrane from its print orientation so its plunger points down toward the tactile switch.
4. Place the membrane under the cap and align its four screw holes.
5. Confirm that the cap moves freely approximately 0.8 mm and returns without rubbing.
6. Adjust the physical switch/actuator height with a designed spacer—not loose tape—if the switch is not actuated consistently across the full cap.

## Closing the enclosure

1. Power the pod off and disconnect USB.
2. Confirm the battery is secure and undamaged.
3. Inspect the tongue, groove, gasket recess, wire routes, and screw bosses for debris.
4. Lay the TPU perimeter gasket flat in the base recess. Do not stretch or twist it.
5. Lower the completed lid vertically so the tongue enters the groove. Never trap a wire under the sealing surface.
6. Insert all four M2 screws and turn each one only two rotations.
7. Tighten gradually in a diagonal cross pattern until the gap is uniform and the gasket is lightly compressed.
8. Do not use a powered screwdriver and do not crush the printed lid.
9. Press the cap at its center and around four edges. It must return every time.
10. Run button, LED, vibration, radio, charging, and power-switch tests before fitting the strap.

## Opening the enclosure

1. End the game, power the pod off, unplug USB, and wait for all LEDs to turn off.
2. Remove the strap plate if it blocks safe handling.
3. Loosen the four lid screws gradually in a diagonal pattern.
4. Lift the lid vertically using equal finger pressure around the rim.
5. Do not insert a metal screwdriver near the battery. If the gasket sticks, use a broad plastic opening pick only at the external shell seam.
6. Keep screws, gasket, cap, membrane, and light ring together in a clean parts tray.
7. Inspect the cell before touching or moving internal wiring. Stop if it is swollen, hot, leaking, punctured, or smells unusual.

## Attachment and safety

Pass a soft 25 mm strap through both slots in the removable plate. The strap should release under abnormal load; do not use a neck lanyard, permanent zip tie, rigid metal band, or strong magnet. Add a replaceable foam pad between the plate and clothing/body. The two attachment screws must end inside their blind bosses and must never protrude into the electronics cavity.

## Validation before active play

- 100 manual presses at the center and four edges.
- 30-minute powered test while worn.
- USB insertion/removal without shell movement.
- Ten open/close service cycles with no loose inserts or boss cracks.
- One-metre controlled drop testing onto wood and carpet with an inert battery substitute first.
- Strap pull/release test using a documented fixture, not a person’s neck or limb.
- Radio-range test in the actual worn orientation.

This prototype is not approved for unsupervised children or commercial sale.

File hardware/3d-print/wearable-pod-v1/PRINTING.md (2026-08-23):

# Printing Instructions

## Print one tolerance coupon first

Print `10-tolerance-coupon.stl` using the same material, nozzle, layer height, and wall settings planned for the housing.

The eight holes from left to right are:

`2.2, 2.3, 2.4, 3.0, 3.1, 3.2, 3.3, 3.4 mm`

Use the first three to select an M2 clearance hole. Use the last five to select the heat-set-insert pilot hole. Change the constants near the top of `generate_models.py` if your printer needs compensation.

## Materials

| Part | Recommended prototype material | Reason |
|---|---|---|
| Base, lid, cap, strap mount, carrier | PETG | Tough, printable, and suitable for functional mechanical parts |
| Button membrane, gasket, bumper | TPU 95A | Flexible, replaceable, and impact absorbing |
| Light ring | Natural/translucent PETG | Diffuses LEDs better than an opaque shell |

PETG is appropriate for prototypes, but do not leave the pod in a closed vehicle in UAE heat. For higher-temperature testing, evaluate ASA or a suitable PC blend using an enclosed printer. Production material selection requires impact, chemical, sweat, UV, flammability, and regulatory review.

## Baseline slicer settings

- 0.4 mm nozzle.
- 0.20 mm layer height; 0.16 mm for the membrane and gasket if available.
- Four perimeters for rigid structural parts.
- Five top and bottom layers.
- 30–40% gyroid or adaptive-cubic infill.
- 100% infill for the gasket and membrane.
- Elephant-foot compensation enabled after measuring the coupon.
- Seam positioned away from USB, switch, gasket, and button-guide surfaces.
- No automatic scaling.

## Orientation

| STL | Build-plate orientation |
|---|---|
| `01-base-shell` | Flat wearer-facing bottom on the plate; cavity upward |
| `02-top-lid` | Flat underside on the plate |
| `03-button-cap` | Retaining flange on the plate; visible face upward |
| `04-button-membrane-tpu` | Flat diaphragm on the plate; plunger upward; flip during assembly |
| `05-perimeter-gasket-tpu` | Flat |
| `06-light-ring-transparent` | Flat |
| `07-drop-bumper-tpu` | Flat |
| `08-strap-mount` | Flat wearer-facing side on the plate |
| `09-electronics-carrier` | Large base plate on the plate |
| `10-tolerance-coupon` | Flat |

The parts are designed to avoid mandatory support. If a printer struggles with the carrier rails, use support from the build plate only and keep support away from board-contact surfaces.

## Acceptance inspection

Reject and reprint a part if it has layer separation, a warped gasket surface, a cracked boss, sharp strings inside the battery compartment, blocked USB/switch access, a cap that rubs or remains depressed, or strap-slot damage.

PETG guidance: [Prusa PETG material documentation](https://help.prusa3d.com/article/petg_2059).

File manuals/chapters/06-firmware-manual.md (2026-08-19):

> Physical Social Games Business | Manual 06 | Version 0.1 | 2026-08-19

# Firmware Manual

## Node firmware modules
Board support; unique identity; input/debounce; event queue; ESP-NOW transport; acknowledgements/retry; LED/haptic patterns; battery monitor; health beacon; configuration storage; diagnostics; signed update placeholder.

## Node state machine
`BOOT -> SELF_TEST -> PAIRING/READY -> ACTIVE -> ELIMINATED/LOCKED -> READY -> LOW_BATTERY -> SHUTDOWN`.

A press is accepted only in ACTIVE, within the configured duration, after debounce, and outside lockout. The node immediately shows a neutral "pending" flash, sends the event, and only shows success after the hub acknowledges it.

## Event packet
```c
struct PressEvent {
  uint8_t version;
  uint8_t device_id;
  uint8_t event_type;
  uint8_t flags;
  uint32_t sequence;
  uint32_t uptime_ms;
  uint16_t battery_mv;
  uint16_t auth_tag;
};
```

## Timing targets
Debounce 25 ms; valid press 80-900 ms; hold event at configurable 1,500 or 3,000 ms; local input lockout 1,000 ms; health beacon 2 s; event acknowledgement target under 120 ms; reconnect target under 5 s.

## Hub firmware
Maintain allow-listed node MACs/IDs, receive and deduplicate packets, translate to normalized game events, persist the last state snapshot, serve local web assets, broadcast WebSocket updates, log diagnostics, and send effect/state commands back to nodes.

## Security baseline
Use per-kit keys, allow-listed devices, a random kit Wi-Fi password, no open debug endpoints in a sale unit, no default cloud credential, monotonic sequence handling, and signed firmware updates before commercial launch. Security is a release requirement even when gameplay data seems harmless.

## Development workflow
Use PlatformIO or ESP-IDF with a reproducible lockfile/toolchain. Keep node and hub projects in one repository with shared packet definitions and tests. Every release gets a semantic version, build hash, protocol version, and migration note.

## Firmware test instruction
Unit-test debounce and state transitions; fuzz malformed packets; simulate duplicate/out-of-order packets; power-cycle during game; run 1,000 presses per node; measure latency distribution; test weak signal; test a dead node; and verify that a stale packet cannot re-eliminate or re-score.

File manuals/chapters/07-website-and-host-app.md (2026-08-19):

> Physical Social Games Business | Manual 07 | Version 0.1 | 2026-08-19

# Website and Host App

## MVP surface
A responsive local web app served by the hub. The host joins the kit Wi-Fi, opens the local address/QR code, creates players, assigns node IDs, selects a game, performs a device check, and starts.

## Required screens
Welcome/connect; create session; player names; button assignment; game library; rule configuration; preflight device check; live game dashboard; pause/abort; winner/results; diagnostics; export log.

## Live dashboard
Show game title and round, timer, player cards, alive/eliminated or score state, team colors, connection and battery warnings, recent event feed, pause, and emergency end. The host must never need to scroll to reach pause/end on a phone.

## Interaction rules
Use large touch targets, high contrast, color plus icon/text status, visible confirmation for destructive actions, and an offline indicator. Do not rely on sound alone. Avoid mandatory accounts or phone numbers for the prototype.

## QR joining
For the MVP, QR opens the host page on the local hub network; players do not need individual phones. Later, optional spectators can join a read-only screen. Do not expose control URLs without session authorization.

## Suggested stack
TypeScript, Vite, React or lightweight vanilla components, CSS variables/design tokens, and WebSocket transport. Build to static assets embedded in the hub filesystem. Use a shared JSON schema for normalized game events.

## Acceptance tests
360 px phone width; latest Chrome/Edge/Safari UI rendering; no internet; reconnect after the phone locks; large player names; six simultaneous events; timer drift; low battery warning; pause/resume; and safe recovery after hub refresh.

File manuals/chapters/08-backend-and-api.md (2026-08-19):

> Physical Social Games Business | Manual 08 | Version 0.1 | 2026-08-19

# Backend and API

## MVP decision
Keep the authoritative backend on the local hub. Cloud is not required to play. This prevents venue internet from becoming a gameplay dependency and keeps the privacy footprint small.

## Local endpoints
- `GET /api/kit` - identity, firmware, protocol, battery summary.
- `POST /api/session` - create a new game session.
- `POST /api/session/{id}/players` - assign player and device.
- `POST /api/session/{id}/start|pause|resume|end` - controlled transitions.
- `GET /api/session/{id}` - current snapshot.
- `WS /ws/session/{id}` - real-time events and state patches.
- `GET /api/diagnostics/export` - support log without personal history by default.

## Event flow
Hardware events are normalized before the game engine sees them. The engine produces domain events such as `PLAYER_ELIMINATED`, `POINT_STOLEN`, or `SEQUENCE_ADVANCED`. The state reducer is deterministic; replaying the same ordered domain events must produce the same state.

## Cloud phase
Add optional accounts, game catalogue updates, telemetry consent, customer support, purchases, and cross-device history only after the local game is stable. Use regional/legal review for hosting and transfers, encrypt in transit and at rest, and collect the minimum necessary data.

## Operational requirements
Structured logs with timestamps and correlation IDs; no secrets in logs; rate limiting; schema validation; idempotency keys for commands; explicit API versioning; device and app compatibility matrix; safe rollback for updates.

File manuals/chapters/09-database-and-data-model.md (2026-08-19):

> Physical Social Games Business | Manual 09 | Version 0.1 | 2026-08-19

# Database and Data Model

## Local model
Use a small embedded store or append-only JSON event log on the hub. Core records: Kit, Device, Player, Session, Team, GameDefinition, GameConfig, RawHardwareEvent, DomainEvent, StateSnapshot, Result, FirmwareVersion.

## Minimal fields
`Device(id, hardware_rev, firmware, battery, last_seen, signal)`; `Session(id, game_id, created_at, started_at, ended_at, status, config_version)`; `Player(id, display_name, device_id, team_id)`; `Event(id, session_id, sequence, source, type, payload, received_at)`.

## Data rules
Display names can be temporary nicknames; delete session names after a configurable period; do not collect birth dates, exact location, contacts, photos, audio, or biometrics. Separate operational telemetry from gameplay history and use explicit consent for cloud analytics.

## Retention default
Raw radio diagnostics: seven days on support builds, disabled or bounded in production. Local session history: last 20 sessions unless the host clears it. Cloud customer profile: only while the account is active plus a documented legal/operational retention period.

## Migration and backup
Version every schema and game definition. Apply forward migrations with a backup/snapshot. If migration fails, preserve the previous playable version and show a clear support code.

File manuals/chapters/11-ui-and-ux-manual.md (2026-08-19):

> Physical Social Games Business | Manual 11 | Version 0.1 | 2026-08-19

# UI and UX Manual

## Experience target
Open box to first round in under five minutes. The host should answer only: who is playing, which pod belongs to whom, which game, and any optional rule.

## Setup flow
1. Power hub and six pods.
2. Scan QR or join the kit network.
3. Watch six device tiles turn ready.
4. Tap a physical pod; the matching tile animates; enter player name.
5. Choose a game and accept the safety briefing.
6. Run a three-second feedback test and start.

## Status language
Use plain words: Ready, Weak signal, Low battery, Paused, Eliminated, Reconnecting. Pair colors with icons and text. Red means unavailable/eliminated, amber means attention, teal means active/ready, and blue means neutral/system.

## Failure recovery
If a pod drops, pause automatically only when the current game cannot continue fairly. Show which pod failed and a one-tap `Replace device` flow. Preserve the timer and state. Never make the host rebuild all player assignments.

## Accessibility
Minimum 4.5:1 contrast for normal text, 44 px touch targets, scalable type, no meaning by color alone, optional reduced motion, captions/text equivalents for sound, and haptic alternatives. Include low-mobility games and a no-running filter in the library.

## Research script
Observe without coaching: unbox, charge, assign, choose, start, recover one disconnected pod, and explain a result. Record completion time, errors, questions, and confidence. Improve the flow before adding more decoration.

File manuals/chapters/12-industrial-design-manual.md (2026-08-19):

> Physical Social Games Business | Manual 12 | Version 0.1 | 2026-08-19

# Industrial Design Manual

## Design intent
Premium, friendly, obvious to press, comfortable on clothing, and durable enough for repeated gatherings. It should look like a social-game object, not a medical alarm, security tracker, or television-show prop.

## Geometry targets
Consumer goal 55-60 mm diameter, 18-23 mm body depth, under 55 g, 42-48 mm press surface, 1.5-2.5 N activation, rounded R2+ edges, recessed power switch, protected USB-C or contact charging, and a replaceable attachment module.

## CMF direction
Deep navy main shell, soft teal active surface, coral/amber state accents, warm off-white case interior. Matte fine texture hides scratches; glossy light pipe only where needed. Avoid excessive neon and avoid six unrelated toy colors.

## Feedback hierarchy
Host screen carries complex information. Pod feedback stays glanceable: color/state, one short vibration, and rare local sound. Do not expose raw connection codes during normal play.

## Durability goals
Prototype: 1 m drop to wood/carpet, 5,000 presses. Engineering validation: repeated 1.2 m multi-face drops, 100,000 press cycles, sweat/skin-oil wipe tests, 0-45 C operating evaluation, transport vibration, and ingress tests appropriate to the final claim. Never print an IP rating without certified testing.

## Human-factors tests
Different fabrics, abayas/jackets/T-shirts, standing/sitting, left/right hand, reduced grip, accidental leaning, and quick device removal. Test antenna performance while worn, not only on a bench.

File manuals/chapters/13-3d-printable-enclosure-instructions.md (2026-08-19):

> Physical Social Games Business | Manual 13 | Version 0.1 | 2026-08-19

# 3D-Printable Enclosure Instructions

## Parametric starting dimensions
Outer diameter 62 mm; total depth 25 mm; wall 2.0 mm; top-cap travel 0.8 mm; press disk 48 mm; LED light-pipe groove 2.5 mm; PCB standoffs sized to the selected dev board; battery pocket with 0.6-1.0 mm clearance; four M2 heat-set inserts or snap features; clip rail on the back.

## Print recommendation
Print housing in PETG for tougher functional parts; TPU 95A for the press membrane/bumper; 0.2 mm layers; four perimeters; 30-40% infill; orient the back shell flat and the press cap face-up. Keep support away from snap and gasket surfaces.

## Assembly sequence
Deburr; fit heat-set inserts; install switch actuator; place light pipe; mount PCB; route motor and battery without crossing antenna keep-out; secure battery with removable foam tape; add insulation; close shell; fit clip/strap; verify press around the full cap; perform radio and charge tests.

## Safety rules
No exposed screw tips, conductive edges, pinched battery, loose cell, sharp clip, strong neck attachment, or inaccessible power isolation. Reject any printed part with cracks, warped battery pocket, or a cap that can jam down.

## CAD deliverables
Native parametric file, STEP, STL/3MF per part, drawing with critical dimensions/tolerances, exploded assembly, BOM, print orientation sheet, revision table, and a change log tied to playtest findings.

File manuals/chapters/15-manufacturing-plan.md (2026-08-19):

> Physical Social Games Business | Manual 15 | Version 0.1 | 2026-08-19

# Manufacturing Plan

## Phases
EVT validates electronics and radio; DVT validates mechanical design, safety, reliability, and pre-compliance; PVT validates tooling, assembly process, fixtures, yield, packaging, and traceability; mass production begins only after signed exit reports.

## Supplier package
Gerbers, drawings, tolerances, golden sample, approved vendor list, controlled BOM, firmware image/hash, programming/test procedure, cosmetic standards, packaging spec, serial/lot format, change-control process, and defect criteria.

## End-of-line test
Program identity/keys; verify current draw; main press; LED colors; vibration/buzzer; radio packet/ack; RSSI at fixture distance; battery voltage; charge detection; firmware/version; label scan; final visual inspection. Store pass/fail by serial and lot.

## Yield targets
Pilot first-pass yield >=90%; production target >=97% after process stabilization. Any supplier substitution requires documented equivalence and targeted revalidation, especially battery, radio module, antenna materials, switch, plastics, and charger.

## UAE market gates
Wireless telecommunications equipment intended for UAE sale requires TDRA review/type approval under the applicable regime; current service requirements can include technical data sheets and accredited radio/EMF/safety reports. Confirm classification before production: https://tdra.gov.ae/en/Services/service-card?sID=Cu4EDmeifjoQ1zAbgYV59qYlswfGAtcsK_IwGX8c0LQ

Products subject to UAE technical regulations may require a MoIAT conformity certificate and accredited test report: https://moiat.gov.ae/en/services/issue-conformity-certificates-for-regulated-products

Do not print conformity marks, IP ratings, age claims, or certifications until formally earned and documented.

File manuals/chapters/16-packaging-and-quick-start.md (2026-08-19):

> Physical Social Games Business | Manual 16 | Version 0.1 | 2026-08-19

# Packaging and Quick-Start

## Box contents
Six numbered wearable pods, one hub, six attachment straps/clips, one charging solution, USB cable, quick-start card, safety card, game library card/QR, warranty/support information, and inventory checklist.

## Opening experience
The lid shows three steps: power, join, play. Devices sit in numbered wells. Status LEDs are visible during charging. The host should not need to remove a lower tray before learning setup.

## Quick-start copy
1. Charge all pods and power the hub.
2. Place pods high on the upper back using the provided attachment.
3. Scan the hub QR and join the kit network.
4. Tap each pod to assign a player.
5. Choose a game, clear the play area, review the safety rules, and start.

## Safety card
Use only in a clear private play area. No pushing, grabbing, tackling, road/pool/stair play, or device placement on neck/face. Touch only the wearable device. Stop for pain, overheating, damaged battery, cracked housing, or unsafe behavior. MVP use is supervised and 14+.

## Sustainability
Right-size the box, minimize mixed plastics, make paper separable, use replaceable straps, design devices for battery/service access by trained technicians, and avoid a permanently decorative insert that prevents efficient shipping.

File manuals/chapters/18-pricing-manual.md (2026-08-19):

> Physical Social Games Business | Manual 18 | Version 0.1 | 2026-08-19

# Pricing Manual

## Pricing method
Price from landed cost and customer value, not only competitor markup. Landed cost includes product, hub, battery, accessories, packaging, freight, customs, certification amortization, payment fees, warranty reserve, returns, fulfilment, support, and VAT treatment.

## Working model
If mature landed COGS is AED 220-320, a direct-to-consumer price hypothesis of AED 699-999 gives room for payment, fulfilment, warranty, marketing, and channel discounts. Do not publish this range until willingness-to-pay and supplier quotes are tested.

## Validation
Test three concept prices with the same offer; collect purchase intent and deposits, not compliments; compare family-use vs event-use positioning; test whether included games, carry/charging case, and bilingual content increase value; record refund/objection reasons.

## Margin guardrails
Target DTC gross margin before marketing of 55-65% once scaled. Wholesale requires sufficient margin for the retailer and your support/warranty burden. Hardware subscriptions should not be necessary for basic play.

## Offer ladder
Core six-player kit; accessory straps/replacement pods; larger group expansion; paid premium game packs only after a strong free library; event/corporate bundle with facilitation tools; rental for trial and hospitality.

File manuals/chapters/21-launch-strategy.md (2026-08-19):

> Physical Social Games Business | Manual 21 | Version 0.1 | 2026-08-19

# Launch Strategy

## Stage 1 - proof (weeks 1-4)
One-node technical proof, six-node bench test, Pulse Hunt paper prototype, and ten customer interviews. Gate: reliable events and clear demand for active social play.

## Stage 2 - alpha (weeks 5-8)
Wearable housings, local host UI, Pulse Hunt plus Signal Chain and Echo Match, five supervised groups. Gate: repeat play, safe behavior, setup under five minutes.

## Stage 3 - paid pilot (weeks 9-12)
Ten kits or facilitated sessions, deposits/fees, support logs, willingness-to-pay, and supplier DFM review. Gate: no open critical defects and credible unit economics.

## Stage 4 - engineering validation
Custom PCB, DVT enclosure, battery/charger validation, pre-compliance testing, TDRA/MoIAT classification, privacy/legal documents, brand clearance, and pilot manufacturer.

## Stage 5 - controlled UAE launch
Limited inventory, local fulfilment, bilingual quick-start/safety material, responsive support, spare stock, and weekly defect/review meeting. Expand only after return, support, and reliability metrics stabilize.

## Stop conditions
Unsafe common behavior, persistent missed/duplicate hits, less than 50% desire to replay after iteration, setup consistently above ten minutes, supplier cost that destroys contribution margin, or regulatory path inconsistent with the model.

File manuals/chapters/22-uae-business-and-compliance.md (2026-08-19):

> Physical Social Games Business | Manual 22 | Version 0.1 | 2026-08-19

# UAE Business and Compliance

## Business setup
Select the exact activities first: e-commerce/trading of electronic games or toys, software/content, import, and possibly event services. Mainland setup steps include activity, legal form, trade licence, trade name, initial approval, premises, and additional approvals: https://u.ae/en/information-and-services/business/doing-business-on-the-mainland/steps-to-start-a-business-on-the-mainland

A free-zone company may face regulated access to mainland sales, so model the intended sales channel and distributor structure before choosing. Obtain professional UAE legal/accounting advice for the specific emirate and activities.

## Wireless and product conformity
Confirm TDRA equipment classification and supplier registration/type-approval requirements before commercial import or sale. Current policy covers entities involved in registration, approval, import, distribution, display, sale, and commercial use of telecommunications equipment. Start here: https://tdra.gov.ae/en/Services/service-card?sID=Cu4EDmeifjoQ1zAbgYV59qYlswfGAtcsK_IwGX8c0LQ

Confirm whether the kit, battery charger, and toy/electronic classification are regulated under MoIAT conformity programmes. A conformity application for regulated products requires a valid trade licence and accredited test report: https://moiat.gov.ae/en/services/issue-conformity-certificates-for-regulated-products

## Data protection
UAE Federal Decree-Law No. 45 of 2021 creates obligations for personal-data processing, security, consent/other lawful bases, rights, and cross-border transfers. Minimize data and keep MVP play local: https://u.ae/en/about-the-uae/digital-uae/data/data-protection-laws.

## Tax
As of this handbook date, UAE resident businesses must register for VAT when taxable supplies/imports exceed AED 375,000 in the prior 12 months or are expected to exceed it in the next 30 days; voluntary threshold is AED 187,500. Verify current rules and your facts: https://www.tax.gov.ae/en/services/vat.registration.aspx

## Practical compliance file
Trade licence/activities; customs/importer setup; TDRA correspondence and certificate; MoIAT classification/certificate; battery transport documents including UN 38.3; accredited safety/EMC/radio reports; supplier declarations; labels/manuals; risk assessment; privacy notice/terms; warranty/returns; incident/recall plan; serial/lot traceability.

## Important limitation
This manual is a planning checklist, not legal, tax, safety-certification, or regulatory advice. Confirm requirements with the relevant UAE authorities and qualified advisors before sale, import, claims, or children's use.

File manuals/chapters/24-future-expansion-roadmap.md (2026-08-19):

> Physical Social Games Business | Manual 24 | Version 0.1 | 2026-08-19

# Future Expansion Roadmap

## Phase A - prove the platform
Six nodes, one hub, three excellent games, offline host UI, adult/older-teen supervised use, reliable event protocol, and repeat-play evidence.

## Phase B - consumer kit
Custom low-power PCB, certified battery/charging, robust enclosure and attachment, manufactured case, five-game library, bilingual content, updates, diagnostics, and UAE compliance.

## Phase C - library and accessories
Expansion pods to 8/12 players, floor/territory bases, wrist/vest attachments, spectator mode, seasonal game packs, creator tools with rule validation, and accessibility filters.

## Phase D - events and corporate
Multi-kit orchestration, facilitator dashboard, team analytics that avoid intrusive employee profiling, rental fleet management, quick sanitation/service, venue mode, and certified facilitators.

## Phase E - regional/global
Arabic/English localization quality, country-specific radio/product approvals, distributor/service strategy, regional cloud/data review, climate testing, and localized game research.

## Technology options to revisit
Lower-power Nordic radio architecture; charging contacts/case; secure OTA; larger mesh/multi-hub events; UWB only if precise ranging creates a proven game mechanic; motion sensors only after button simplicity is exhausted. Avoid feature creep that weakens reliability or setup.

## North-star metrics
Median setup under five minutes; session success >99%; repeat play within 30 days; games played per kit; support contacts per 100 sessions; return rate; contribution margin; safety incidents; and percentage of active owners using more than one game.

## Next seven actions
Buy the seven-board BOM; build the one-node proof; run a paper Pulse Hunt; implement acknowledged events; assemble six bench nodes; conduct the 1,000-press test; schedule the first supervised playtest and record the scorecard.

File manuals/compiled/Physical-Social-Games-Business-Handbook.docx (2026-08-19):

BUILD MANUAL • VERSION 0.1

Physical Social Games Business

A practical, original, UAE-ready roadmap from playable prototype to launch

Concept render of six wearable game buttons, one hub, and an open carry case

Original concept visualization: six wearable controls plus one hub and carry case.

Prepared as an execution handbook • UAE focus • 19 August 2026

# Executive decision

Build seven devices, not six: six wearable ESP32-C3 nodes and one central hub. Use ESP-NOW node-to-hub and a local Wi-Fi web app. Prove reliability and fun offline before custom electronics, apps, cloud, tooling, or certification spend.

## How to use this handbook

- Read Manual 01 to freeze scope.
- Buy from Manual 04 and build in the order in Manual 05.
- Use Manuals 06-11 for firmware/software implementation.
- Do not run active playtests until Manual 14's bench and safety gates pass.
- Use Manuals 15 and 22-23 before commercial import, claims, or sale.

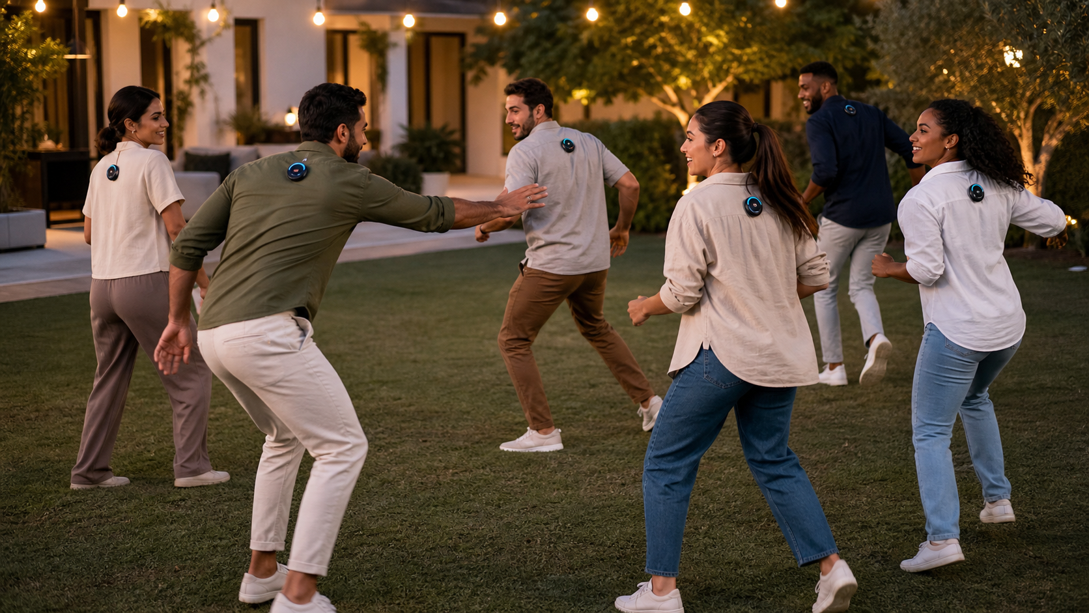
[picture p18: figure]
Six adults safely playing a wearable-button game in a cleared villa garden

Intended experience: social, premium, active, and safe in a cleared private play area.

## Manual index

No. | Manual
01 | Product Specification
02 | Hardware Architecture
03 | Circuit Design
04 | Component List and BOM
05 | Prototype Design
06 | Firmware Manual
07 | Website and Host App
08 | Backend and API
09 | Database and Data Model
10 | Game Engine Design
11 | UI and UX Manual
12 | Industrial Design Manual
13 | 3D-Printable Enclosure Instructions
14 | Testing and Quality Plan
15 | Manufacturing Plan
16 | Packaging and Quick-Start
17 | Branding Manual
18 | Pricing Manual
19 | Business Model Manual
20 | Marketing Manual
21 | Launch Strategy
22 | UAE Business and Compliance
23 | Legal and IP Manual
24 | Future Expansion Roadmap

MANUAL 01

# Product Specification

## Purpose

Define the product to build, who it is for, what the MVP must prove, and what is deliberately postponed.

## Product promise

A reusable box of six wearable electronic controls and one hub that turns a room, garden, majlis, or event space into a library of original real-life games. The physical devices capture deliberate presses; the digital host controls rules, timing, teams, feedback, scoring, and replay.

MVP decision: build six wearable nodes plus one hub. The first release is a supervised prototype for adults and older teens, not a children's toy and not a finished waterproof consumer product.

## Flagship game: Pulse Hunt

Objective: survive until time expires, or as the Hunter eliminate all Runners.

Players: 4-6. One Hunter; 3-5 Runners. For three players, use one Hunter and two Runners with a shorter arena.

Setup: charge and assign one pod per player; clip pods high on the upper back; mark a clear play boundary; remove trip hazards; select 5-8 minutes; give Runners a 20-second head start; test every pod before starting.

Core rules: the Hunter eliminates a Runner by pressing the Runner's pod once until it confirms with light, vibration, and a sound from the host. Only the device may be touched. No grabbing, blocking doorways, tackling, pushing, hiding in locked rooms, stairs, roads, pools, kitchens, or vehicle areas. Eliminated players freeze, raise a hand, and walk to the safe zone.

False-press protection: a valid press is 80-900 ms, followed by a one-second lockout. The hub acknowledges the event. The node changes to red only after acknowledgement; if acknowledgement fails, it vibrates twice and retries.

Winning: Runners win if at least one remains alive at zero. The Hunter wins if all are eliminated. Tie-break: fastest complete elimination time.

Variations: two Hunters; team rescue with a 3-second teammate hold; three-life mode; shrinking arena announced by the host; silent mode using vibration only; score attack where each confirmed tag is one point and eliminated players re-enter after 20 seconds.

## Seven additional original games

Game | Core idea | Button use
Vault Heist | Players steal digital gems while protecting their own vault. | Hold an opponent's pod for 1.5 seconds; a successful steal triggers a cooldown shield.
Signal Chain | Cooperative memory and movement challenge. | LEDs cue a changing player sequence; players press their own pods in order before time runs out.
Guardian Link | Secret pairs protect one another while completing public tasks. | A partner can cancel one hit by pressing the threatened player's pod within three seconds.
Territory Pulse | Teams control physical zones made from detached pods. | Hold a zone pod until its LED changes to the team's color; control scores over time.
Echo Match | Fast reaction and pattern recognition. | Players copy color/sound patterns on their own pods; fastest accurate response scores.
Silent Mission | Hidden individual objectives inside a normal gathering. | Short and long presses log secret actions; the host reveals completed missions at the end.
Relay Rush | Cooperative race against a dynamic route. | The host lights the next player's pod; correct presses pass the signal, mistakes add time.

## Target user and occasion

Primary: UAE families and friend groups aged 14+, playing at villas, ghabgas, majlis-adjacent spaces, parks, and private gatherings. Secondary: birthdays, youth groups, hospitality venues, and later corporate events. The host should understand setup within three minutes and start a game within five.

## MVP acceptance criteria

- Six nodes connect through one hub without manual repair during a 30-minute session.
- A physical press appears in the UI within 200 ms at 95th percentile in the intended arena.
- At least 99.5% of deliberate valid presses are registered in a 1,000-press bench test.
- No duplicate scoring from one press; every event has a sequence number and acknowledgement.
- A new host can set up Pulse Hunt using only the quick-start page.
- In three playtests, at least 70% of participants request another round and rate fun at 4/5 or higher.

## Not in MVP

Native iOS/Android apps, cloud accounts, children under 14, public matchmaking, GPS, microphones, cameras, precise location tracking, custom injection-moulded tooling, certified waterproofing, and mass-production charging cases.

## Product risks and response

Accidental activation: use force/travel tuning, press windows, lockouts, hub acknowledgement, and playtesting. Unsafe chasing: strict arena rules, age gate, host briefing, and game modes that do not require running. Wireless dropouts: local star topology, retries, health beacons, and no cloud dependency. One-game novelty: ship only after three mechanics test well, then expand the library through software.

## Build instruction

Freeze this MVP specification for the first prototype sprint. New ideas go into a backlog unless they affect safety, event reliability, or the fun hypothesis.

MANUAL 02

# Hardware Architecture

Offline-first architecture: six wearables use ESP-NOW to a hub, which serves a local web app

Figure 1. MVP communication path: local, acknowledged, and independent of venue internet.

## Recommended MVP architecture

Use six Seeed XIAO ESP32-C3 wearable nodes plus one XIAO ESP32-C3 hub. Nodes send compact events to the hub over ESP-NOW. The hub runs a local Wi-Fi access point and WebSocket server; a phone or laptop joins the hub network and opens the local web interface. Internet is optional.

[6 wearable nodes] -- ESP-NOW --> [hub] -- local Wi-Fi/WebSocket --> [phone/laptop browser]

This is better for the proof-of-concept than connecting six BLE peripherals directly to a phone: the host pairs once with the hub, the game works offline, event timing is centralized, and browser/device Bluetooth differences are removed. ESP32-C3 supports 2.4 GHz Wi-Fi and Bluetooth LE 5, so the same dev board preserves experimentation options. Official overview: https://docs.espressif.com/projects/esp-hardware-design-guidelines/en/latest/esp32c3/product-overview.html

## Node blocks

- XIAO ESP32-C3 module with antenna kept clear of battery and metal clip.
- Large momentary switch under a soft press cap.
- Addressable RGB LED or a 6-8 LED ring for player/status feedback.
- Coin vibration motor driven through a MOSFET.
- Optional piezo buzzer; keep node audio subtle and let the host produce most sound.
- 500 mAh protected LiPo, slide power switch, and USB-C charging through the board.
- Prototype enclosure with breakaway fabric strap or rounded clip.

## Hub blocks

- XIAO ESP32-C3 connected to USB power.
- ESP-NOW receiver and event authority.
- Local Wi-Fi access point, HTTP server, and WebSocket endpoint.
- USB serial debug channel; optional OLED only for diagnostics.

## Protocol

Each node sends device_id, event_type, sequence, node_time_ms, battery percentage, and a message authentication/check value. The hub deduplicates by device plus sequence, timestamps receipt, applies the game rule, and replies with an acknowledgement containing the accepted state. Retry at 40, 100, and 220 ms with random jitter, then show a local error pattern.

## Range target

Design for 25 m reliable line-of-sight and 10-15 m through typical villa partitions. Do not market a range until measured. Test the exact antenna orientation with the pod worn against different fabrics and body positions because the human body attenuates 2.4 GHz.

## Consumer architecture after validation

Re-evaluate a Nordic nRF52-class design for lower power and a robust proprietary 2.4 GHz/BLE hub. The nRF52840 supports Bluetooth LE, Bluetooth Mesh, NFC, Thread, and Zigbee, but it raises firmware/tooling and unit-cost complexity. Official product page: https://www.nordicsemi.com/products/nrf52840

## Battery and thermal targets

Active play: 8 hours minimum; shelf-off leakage: under 5% per month; charge time under 2.5 hours; protected cell; enclosure surface below 42 C in normal use. For the MVP, measure actual current in idle, active radio, LED animation, vibration, and power-off states before claiming runtime.

## Reliability rules

- The hub, not the node, owns the official game state.
- Never award points from an unacknowledged local press.
- Every node emits a health beacon every two seconds during a game.
- The UI warns at low battery, weak signal, or missed beacons.
- A reconnecting node requests current state before accepting gameplay input.

## Decision gate

Keep ESP-NOW through the first three playtest rounds. Change radio architecture only if measured packet loss, range, power, platform compatibility, or certification economics fail the targets.

MANUAL 03

# Circuit Design

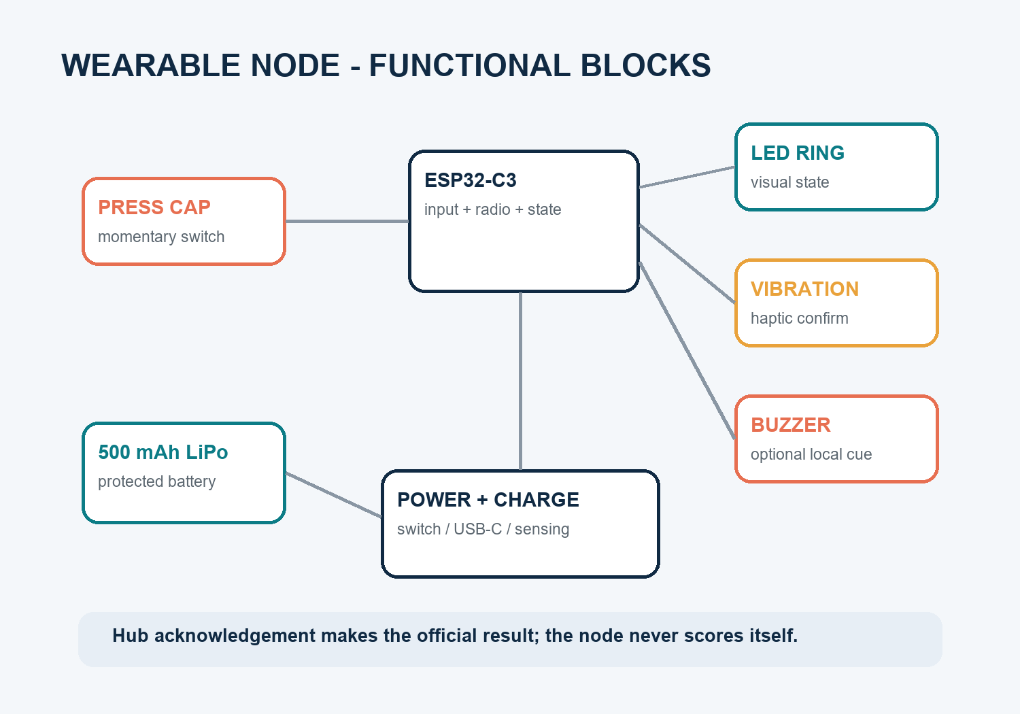
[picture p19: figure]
Wearable node functional block diagram showing press, ESP32-C3, LED, vibration, buzzer, battery, and charging

Figure 2. Functional node blocks; the hub remains the authority for state and scoring.

## Prototype node wiring

Function | XIAO ESP32-C3 pin | Circuit instruction
Main press | D1 / GPIO3 | Switch to GND; enable internal pull-up; add 100 nF only if software debounce is insufficient.
RGB LED | D2 / GPIO4 | WS2812 data through 330 ohm series resistor; 100 uF across LED supply; limit brightness in firmware.
Buzzer | D3 / GPIO5 | Drive piezo or magnetic buzzer through an NPN transistor and base resistor; add flyback protection if inductive.
Vibration | D4 / GPIO6 | Logic-level N-MOSFET low-side drive; flyback diode across coin motor; 100 nF motor suppression.
Battery sense | D0 / GPIO2 | 220 k/100 k divider to ADC; enable through a transistor if idle leakage matters.
Power | BAT and GND | Protected 3.7 V LiPo to battery pads; physical slide switch in series for a true off state.

## Electrical rules

Keep the 2.4 GHz antenna edge free of copper, battery, motor, steel clip, and fingers. Place motor and buzzer away from the antenna. Add test pads for 3V3, GND, button, LED data, UART TX/RX, and battery. Use keyed battery connectors and strain relief. Do not charge unattended during early prototypes.

## Switch and press design

The large visible cap should transfer force to a small rated tactile switch without side-loading it. Start with 1.5-2.5 N actuation and 0.5-1.0 mm perceived travel. The enclosure must prevent clothing pressure from maintaining the switch. A raised protective rim helps but must not make intentional presses difficult.

## Protection for a production PCB

Include reverse-polarity protection, LiPo over-charge/over-discharge/short protection, USB ESD protection, motor transient suppression, programming pads, a reset method, and a current-measurement link. Use only a certified battery pack and document cell traceability.

## Verification instruction

Before connecting a battery, perform continuity and resistance checks. Power from a current-limited bench supply at 3.8 V with a 150 mA limit, confirm quiescent current, then test each output separately. Record peak current during LED white, motor start, radio transmit, and combined worst case.

## Production handoff outputs

Schematic PDF, ERC-clean source, PCB layout, Gerbers, drill files, pick-and-place, BOM with manufacturer part numbers and alternates, test-point map, programming fixture drawing, and a written bring-up procedure.

MANUAL 04

# Component List and BOM

## Buy list for one seven-board MVP

Item | Qty | Planning cost (AED) | Notes
Seeed XIAO ESP32-C3 | 7 | 210-315 | Six nodes plus one hub; buy one spare if budget allows.
Protected 500 mAh LiPo | 6 | 90-150 | Use reputable packs with correct polarity and connectors.
Large momentary switches/caps | 8 | 35-80 | Six plus spares; prototype arcade or low-profile caps.
RGB LEDs/rings | 8 | 40-90 | One per node plus spares.
Coin vibration motors | 8 | 40-80 | Optional in prototype round one but recommended.
Buzzers, MOSFETs, diodes, passives | 1 lot | 35-70 | Breadboard/protoboard stage.
Power switches and wire/connectors | 1 lot | 30-60 | Add strain relief and insulation.
USB-C charging cable set/charger | 1 | 45-90 | Multi-port quality charger; never use damaged cells.
Prototype enclosures/straps/clips | 6 | 90-180 | 3D printing, hook-and-loop, fabric straps.
Hub case and optional OLED | 1 | 35-75 | OLED is diagnostic, not required.

Expected prototype total: approximately AED 615-1,190 before tools, shipping, and failed parts. This is a planning range, not a supplier quote.

## Required tools

Temperature-controlled soldering iron, lead-free or appropriately handled solder, flux, flush cutters, wire stripper, heat-shrink, multimeter, USB power meter, bench supply with current limit, small scale/calipers, and access to a 3D printer. A basic logic analyser is useful for debugging.

## Supplier discipline

Record supplier, order date, exact MPN, lot/batch, price, lead time, datasheet URL, and substitute. Do not silently swap batteries, radios, switches, or plastics. For each critical part maintain one approved alternate and document the validation needed after substitution.

## Cost-down ladder

Prototype dev boards first; then one custom PCB; then panelized PCBs and a simple machined/printed enclosure; only after demand validation consider injection moulding and a charging case. Do not spend on tooling before event reliability and repeat-play are proven.

MANUAL 05

# Prototype Design

## Prototype stages

P0 - one-button proof: one node, one hub, one browser. Demonstrate press, acknowledgement, UI state, and reconnect.

P1 - six wired-on-bench nodes: six powered nodes on a table. Run 1,000 scripted/manual presses, duplicates, simultaneous events, resets, and low-signal tests.

P2 - wearable alpha: battery power, 3D-printed housings, straps/clips, LED and vibration. Conduct controlled walking-speed games.

P3 - playtest kit: refined enclosures, labelled IDs, carry tray, charging checklist, host guide, and three complete game modes.

## Enclosure target

Prototype diameter 58-65 mm; depth 20-28 mm; mass below 70 g; 45-50 mm press area; minimum 2 mm rounded shell walls; no sharp external corners; recessed power switch; USB-C access that cannot be hit during play. Use a replaceable fabric/clip interface so the electronics do not need redesign when wear testing changes.

## Attachment

Start with a wide hook-and-loop armband/back strap plus a rounded clip adapter. Avoid strong magnets near medical devices and avoid lanyards or neck mounting. A production attachment should release under abnormal load and must not use a sharp metal edge against the body.

## Build order

1. Flash unique IDs and radio keys onto all boards.
2. Assemble hub and verify all six nodes on USB power.
3. Add one battery-powered node and measure current/temperature.
4. Clone the validated wiring to the other five.
5. Print one enclosure, conduct fit/press/antenna checks, then print the set.
6. Run bench reliability before any active play.
7. Run a safety briefing and low-speed playtest before chase variants.

## Exit criteria

Six nodes run 30 minutes without a reset, every node reconnects within five seconds after power cycling, the host sees battery/signal status, and two unfamiliar hosts can set up using the quick-start instructions.

MANUAL 06

# Firmware Manual

## Node firmware modules

Board support; unique identity; input/debounce; event queue; ESP-NOW transport; acknowledgements/retry; LED/haptic patterns; battery monitor; health beacon; configuration storage; diagnostics; signed update placeholder.

## Node state machine

BOOT -> SELF_TEST -> PAIRING/READY -> ACTIVE -> ELIMINATED/LOCKED -> READY -> LOW_BATTERY -> SHUTDOWN.

A press is accepted only in ACTIVE, within the configured duration, after debounce, and outside lockout. The node immediately shows a neutral "pending" flash, sends the event, and only shows success after the hub acknowledges it.

## Event packet

struct PressEvent {

uint8_t version;

uint8_t device_id;

uint8_t event_type;

uint8_t flags;

uint32_t sequence;

uint32_t uptime_ms;

uint16_t battery_mv;

uint16_t auth_tag;

};

## Timing targets

Debounce 25 ms; valid press 80-900 ms; hold event at configurable 1,500 or 3,000 ms; local input lockout 1,000 ms; health beacon 2 s; event acknowledgement target under 120 ms; reconnect target under 5 s.

## Hub firmware

Maintain allow-listed node MACs/IDs, receive and deduplicate packets, translate to normalized game events, persist the last state snapshot, serve local web assets, broadcast WebSocket updates, log diagnostics, and send effect/state commands back to nodes.

## Security baseline

Use per-kit keys, allow-listed devices, a random kit Wi-Fi password, no open debug endpoints in a sale unit, no default cloud credential, monotonic sequence handling, and signed firmware updates before commercial launch. Security is a release requirement even when gameplay data seems harmless.

## Development workflow

Use PlatformIO or ESP-IDF with a reproducible lockfile/toolchain. Keep node and hub projects in one repository with shared packet definitions and tests. Every release gets a semantic version, build hash, protocol version, and migration note.

## Firmware test instruction

Unit-test debounce and state transitions; fuzz malformed packets; simulate duplicate/out-of-order packets; power-cycle during game; run 1,000 presses per node; measure latency distribution; test weak signal; test a dead node; and verify that a stale packet cannot re-eliminate or re-score.

MANUAL 07

# Website and Host App

## MVP surface

A responsive local web app served by the hub. The host joins the kit Wi-Fi, opens the local address/QR code, creates players, assigns node IDs, selects a game, performs a device check, and starts.

## Required screens

Welcome/connect; create session; player names; button assignment; game library; rule configuration; preflight device check; live game dashboard; pause/abort; winner/results; diagnostics; export log.

## Live dashboard

Show game title and round, timer, player cards, alive/eliminated or score state, team colors, connection and battery warnings, recent event feed, pause, and emergency end. The host must never need to scroll to reach pause/end on a phone.

## Interaction rules

Use large touch targets, high contrast, color plus icon/text status, visible confirmation for destructive actions, and an offline indicator. Do not rely on sound alone. Avoid mandatory accounts or phone numbers for the prototype.

## QR joining

For the MVP, QR opens the host page on the local hub network; players do not need individual phones. Later, optional spectators can join a read-only screen. Do not expose control URLs without session authorization.

## Suggested stack

TypeScript, Vite, React or lightweight vanilla components, CSS variables/design tokens, and WebSocket transport. Build to static assets embedded in the hub filesystem. Use a shared JSON schema for normalized game events.

## Acceptance tests

360 px phone width; latest Chrome/Edge/Safari UI rendering; no internet; reconnect after the phone locks; large player names; six simultaneous events; timer drift; low battery warning; pause/resume; and safe recovery after hub refresh.

MANUAL 08

# Backend and API

## MVP decision

Keep the authoritative backend on the local hub. Cloud is not required to play. This prevents venue internet from becoming a gameplay dependency and keeps the privacy footprint small.

## Local endpoints

- `GET /api/kit` - identity, firmware, protocol, battery summary.
- `POST /api/session` - create a new game session.
- `POST /api/session/{id}/players` - assign player and device.
- `POST /api/session/{id}/start|pause|resume|end` - controlled transitions.
- `GET /api/session/{id}` - current snapshot.
- `WS /ws/session/{id}` - real-time events and state patches.
- `GET /api/diagnostics/export` - support log without personal history by default.

## Event flow

Hardware events are normalized before the game engine sees them. The engine produces domain events such as PLAYER_ELIMINATED, POINT_STOLEN, or SEQUENCE_ADVANCED. The state reducer is deterministic; replaying the same ordered domain events must produce the same state.

## Cloud phase

Add optional accounts, game catalogue updates, telemetry consent, customer support, purchases, and cross-device history only after the local game is stable. Use regional/legal review for hosting and transfers, encrypt in transit and at rest, and collect the minimum necessary data.

## Operational requirements

Structured logs with timestamps and correlation IDs; no secrets in logs; rate limiting; schema validation; idempotency keys for commands; explicit API versioning; device and app compatibility matrix; safe rollback for updates.

MANUAL 09

# Database and Data Model

## Local model

Use a small embedded store or append-only JSON event log on the hub. Core records: Kit, Device, Player, Session, Team, GameDefinition, GameConfig, RawHardwareEvent, DomainEvent, StateSnapshot, Result, FirmwareVersion.

## Minimal fields

Device(id, hardware_rev, firmware, battery, last_seen, signal); Session(id, game_id, created_at, started_at, ended_at, status, config_version); Player(id, display_name, device_id, team_id); Event(id, session_id, sequence, source, type, payload, received_at).

## Data rules

Display names can be temporary nicknames; delete session names after a configurable period; do not collect birth dates, exact location, contacts, photos, audio, or biometrics. Separate operational telemetry from gameplay history and use explicit consent for cloud analytics.

## Retention default

Raw radio diagnostics: seven days on support builds, disabled or bounded in production. Local session history: last 20 sessions unless the host clears it. Cloud customer profile: only while the account is active plus a documented legal/operational retention period.

## Migration and backup

Version every schema and game definition. Apply forward migrations with a backup/snapshot. If migration fails, preserve the previous playable version and show a clear support code.

MANUAL 10

# Game Engine Design

## Principle

Hardware emits simple physical facts; game definitions decide meaning. A PRESS must not be hard-coded as elimination because the same input may steal points, capture a zone, confirm a sequence, rescue a teammate, or complete a mission.

## Engine components

Game manifest; configuration schema; player/team allocator; deterministic reducer; timers; random seed service; rule validators; effect dispatcher; score/winner evaluator; pause/recovery; replay log.

## Normalized inputs

PRESS, HOLD_STARTED, HOLD_COMPLETED, RELEASE, DEVICE_ONLINE, DEVICE_OFFLINE, BATTERY_LOW, and host commands. The engine accepts only validated inputs from known devices in the current session.

## Game definition contract

Each game declares player range, age guidance, space and activity level, setup, allowed roles, defaults, event handlers, state shape, feedback effects, winner conditions, timeouts, reconnection policy, safety warning, and analytics events.

## Determinism

Store the random seed at session creation. Timers are derived from the hub monotonic clock. Every state change emits an immutable domain event. This makes bugs reproducible and supports match replay without video or personal tracking.

## New-game checklist

Write a one-sentence fun promise; define player choices; identify the physical action; cap downtime; add a comeback path; specify ambiguous simultaneous events; define disconnection behavior; run a paper prototype; then implement. Reject games whose novelty depends only on changing colors or scores.

## Portfolio balance

Launch library target: one chase game, one team strategy game, one cooperative memory game, one low-mobility social/hidden-mission game, and one reaction game. This makes the kit useful across villas, indoor gatherings, mixed mobility, and short/long sessions.

MANUAL 11

# UI and UX Manual

## Experience target

Open box to first round in under five minutes. The host should answer only: who is playing, which pod belongs to whom, which game, and any optional rule.

## Setup flow

1. Power hub and six pods.
2. Scan QR or join the kit network.
3. Watch six device tiles turn ready.
4. Tap a physical pod; the matching tile animates; enter player name.
5. Choose a game and accept the safety briefing.
6. Run a three-second feedback test and start.

## Status language

Use plain words: Ready, Weak signal, Low battery, Paused, Eliminated, Reconnecting. Pair colors with icons and text. Red means unavailable/eliminated, amber means attention, teal means active/ready, and blue means neutral/system.

## Failure recovery

If a pod drops, pause automatically only when the current game cannot continue fairly. Show which pod failed and a one-tap Replace device flow. Preserve the timer and state. Never make the host rebuild all player assignments.

## Accessibility

Minimum 4.5:1 contrast for normal text, 44 px touch targets, scalable type, no meaning by color alone, optional reduced motion, captions/text equivalents for sound, and haptic alternatives. Include low-mobility games and a no-running filter in the library.

## Research script

Observe without coaching: unbox, charge, assign, choose, start, recover one disconnected pod, and explain a result. Record completion time, errors, questions, and confidence. Improve the flow before adding more decoration.

MANUAL 12

# Industrial Design Manual

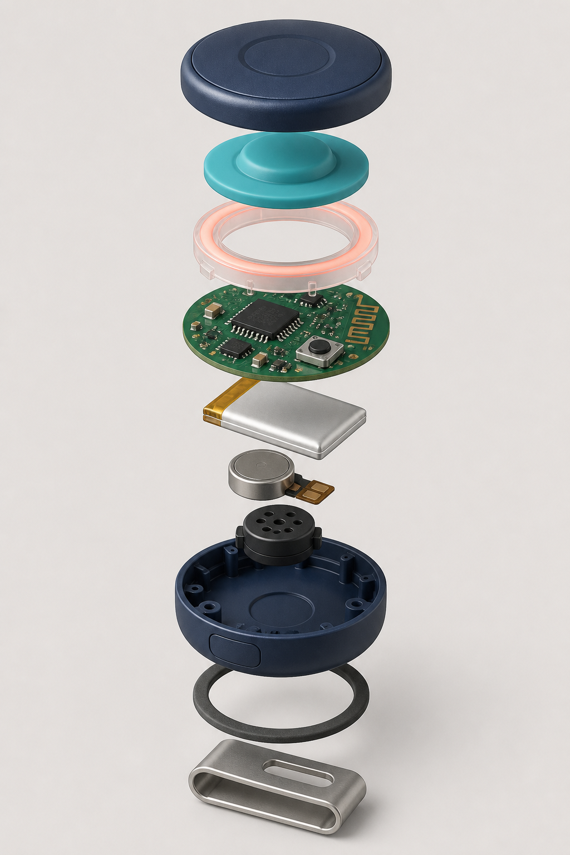
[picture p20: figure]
Exploded product concept with cap, silicone actuator, light pipe, PCB, battery, haptic and audio parts, shell, gasket, and clip

Figure 3. Concept assembly: cap, silicone actuator, light pipe, PCB, cell, haptic/audio parts, shell, gasket, and clip.

## Design intent

Premium, friendly, obvious to press, comfortable on clothing, and durable enough for repeated gatherings. It should look like a social-game object, not a medical alarm, security tracker, or television-show prop.

## Geometry targets

Consumer goal 55-60 mm diameter, 18-23 mm body depth, under 55 g, 42-48 mm press surface, 1.5-2.5 N activation, rounded R2+ edges, recessed power switch, protected USB-C or contact charging, and a replaceable attachment module.

## CMF direction

Deep navy main shell, soft teal active surface, coral/amber state accents, warm off-white case interior. Matte fine texture hides scratches; glossy light pipe only where needed. Avoid excessive neon and avoid six unrelated toy colors.

## Feedback hierarchy

Host screen carries complex information. Pod feedback stays glanceable: color/state, one short vibration, and rare local sound. Do not expose raw connection codes during normal play.

## Durability goals

Prototype: 1 m drop to wood/carpet, 5,000 presses. Engineering validation: repeated 1.2 m multi-face drops, 100,000 press cycles, sweat/skin-oil wipe tests, 0-45 C operating evaluation, transport vibration, and ingress tests appropriate to the final claim. Never print an IP rating without certified testing.

## Human-factors tests

Different fabrics, abayas/jackets/T-shirts, standing/sitting, left/right hand, reduced grip, accidental leaning, and quick device removal. Test antenna performance while worn, not only on a bench.

MANUAL 13

# 3D-Printable Enclosure Instructions

## Parametric starting dimensions

Outer diameter 62 mm; total depth 25 mm; wall 2.0 mm; top-cap travel 0.8 mm; press disk 48 mm; LED light-pipe groove 2.5 mm; PCB standoffs sized to the selected dev board; battery pocket with 0.6-1.0 mm clearance; four M2 heat-set inserts or snap features; clip rail on the back.

## Print recommendation

Print housing in PETG for tougher functional parts; TPU 95A for the press membrane/bumper; 0.2 mm layers; four perimeters; 30-40% infill; orient the back shell flat and the press cap face-up. Keep support away from snap and gasket surfaces.

## Assembly sequence

Deburr; fit heat-set inserts; install switch actuator; place light pipe; mount PCB; route motor and battery without crossing antenna keep-out; secure battery with removable foam tape; add insulation; close shell; fit clip/strap; verify press around the full cap; perform radio and charge tests.

## Safety rules

No exposed screw tips, conductive edges, pinched battery, loose cell, sharp clip, strong neck attachment, or inaccessible power isolation. Reject any printed part with cracks, warped battery pocket, or a cap that can jam down.

## CAD deliverables

Native parametric file, STEP, STL/3MF per part, drawing with critical dimensions/tolerances, exploded assembly, BOM, print orientation sheet, revision table, and a change log tied to playtest findings.

MANUAL 14

# Testing and Quality Plan

## Test layers

Electrical bring-up; firmware unit/integration; radio performance; battery/charge; mechanical durability; usability/setup; gameplay/fun; safety; environmental; manufacturing end-of-line; regulatory pre-compliance.

## Critical tests

- 1,000 deliberate presses per node: target >=99.5% registered, zero duplicate scoring.
- Six-node burst and simultaneous press test.
- 30-minute continuous session plus four-hour soak.
- Power-cycle node/hub during play and recover without corrupting state.
- Range map in villa rooms, garden, through one/two walls, and while worn.
- Battery runtime and charge-temperature logging across six samples.
- Drop, strap pull, repeated clip use, sweat wipe, and button cycle tests.

## Playtest scorecard

Setup minutes; rules explanation minutes; rounds played; fun 1-5; fairness 1-5; physical comfort 1-5; confusion incidents; false activations; missed activations; safety interventions; quote/request for replay.

## Defect severity

P0: safety, battery, electric shock, data exposure, or uncontrolled heat - stop test and quarantine. P1: wrong winner, lost/duplicate event, unrecoverable disconnect - blocks release. P2: confusing flow or recoverable fault - fix before external beta. P3: polish/cosmetic - prioritize by frequency.

## Release gate

No open P0/P1 defects; all acceptance criteria evidenced; firmware/version locked; six-device serial list recorded; quick-start matches build; risk assessment reviewed; support recovery tested by someone outside the build team.

MANUAL 15

# Manufacturing Plan

## Phases

EVT validates electronics and radio; DVT validates mechanical design, safety, reliability, and pre-compliance; PVT validates tooling, assembly process, fixtures, yield, packaging, and traceability; mass production begins only after signed exit reports.

## Supplier package

Gerbers, drawings, tolerances, golden sample, approved vendor list, controlled BOM, firmware image/hash, programming/test procedure, cosmetic standards, packaging spec, serial/lot format, change-control process, and defect criteria.

## End-of-line test

Program identity/keys; verify current draw; main press; LED colors; vibration/buzzer; radio packet/ack; RSSI at fixture distance; battery voltage; charge detection; firmware/version; label scan; final visual inspection. Store pass/fail by serial and lot.

## Yield targets

Pilot first-pass yield >=90%; production target >=97% after process stabilization. Any supplier substitution requires documented equivalence and targeted revalidation, especially battery, radio module, antenna materials, switch, plastics, and charger.

## UAE market gates

Wireless telecommunications equipment intended for UAE sale requires TDRA review/type approval under the applicable regime; current service requirements can include technical data sheets and accredited radio/EMF/safety reports. Confirm classification before production: https://tdra.gov.ae/en/Services/service-card?sID=Cu4EDmeifjoQ1zAbgYV59qYlswfGAtcsK_IwGX8c0LQ

Products subject to UAE technical regulations may require a MoIAT conformity certificate and accredited test report: https://moiat.gov.ae/en/services/issue-conformity-certificates-for-regulated-products

Do not print conformity marks, IP ratings, age claims, or certifications until formally earned and documented.

MANUAL 16

# Packaging and Quick-Start

## Box contents

Six numbered wearable pods, one hub, six attachment straps/clips, one charging solution, USB cable, quick-start card, safety card, game library card/QR, warranty/support information, and inventory checklist.

## Opening experience

The lid shows three steps: power, join, play. Devices sit in numbered wells. Status LEDs are visible during charging. The host should not need to remove a lower tray before learning setup.

## Quick-start copy

1. Charge all pods and power the hub.
2. Place pods high on the upper back using the provided attachment.
3. Scan the hub QR and join the kit network.
4. Tap each pod to assign a player.
5. Choose a game, clear the play area, review the safety rules, and start.

## Safety card

Use only in a clear private play area. No pushing, grabbing, tackling, road/pool/stair play, or device placement on neck/face. Touch only the wearable device. Stop for pain, overheating, damaged battery, cracked housing, or unsafe behavior. MVP use is supervised and 14+.

## Sustainability

Right-size the box, minimize mixed plastics, make paper separable, use replaceable straps, design devices for battery/service access by trained technicians, and avoid a permanently decorative insert that prevents efficient shipping.

MANUAL 17

# Branding Manual

## Positioning

A modern physical play platform that makes gatherings active, surprising, and replayable. The brand is original and should never depend on a television programme, copied terminology, name-tag imagery, or recognizable show styling.

## Working brand criteria

Short in Arabic and English, easy to pronounce, broad enough for many game types, available as a UAE trademark/domain/social handle, and not descriptive of only chasing or buttons. Do not select a final name before clearance.

## Personality

Premium but welcoming; energetic without aggression; clever without being complicated; locally relevant without stereotypes. Use concise host language and celebratory feedback.

## Visual direction

Deep navy foundation, teal action color, coral highlight, amber reward, warm off-white background. Rounded geometry echoes the pod without making every graphic a button. Photography shows real groups and safe open spaces, not staged combat poses.

## Voice examples

Prefer: "Choose a game. Clip in. Start the round." "Six ready." "Signal confirmed." Avoid: militaristic language, copied show phrases, humiliation after elimination, and claims such as "unbreakable" or "works everywhere."

## Naming sprint

Generate 50 candidates; remove narrow/copycat names; screen search engines, domains, app stores, trade names, and trademarks; test pronunciation with Arabic/English speakers; shortlist five; obtain professional clearance; then design the identity.

MANUAL 18

# Pricing Manual

## Pricing method

Price from landed cost and customer value, not only competitor markup. Landed cost includes product, hub, battery, accessories, packaging, freight, customs, certification amortization, payment fees, warranty reserve, returns, fulfilment, support, and VAT treatment.

## Working model

If mature landed COGS is AED 220-320, a direct-to-consumer price hypothesis of AED 699-999 gives room for payment, fulfilment, warranty, marketing, and channel discounts. Do not publish this range until willingness-to-pay and supplier quotes are tested.

## Validation

Test three concept prices with the same offer; collect purchase intent and deposits, not compliments; compare family-use vs event-use positioning; test whether included games, carry/charging case, and bilingual content increase value; record refund/objection reasons.

## Margin guardrails

Target DTC gross margin before marketing of 55-65% once scaled. Wholesale requires sufficient margin for the retailer and your support/warranty burden. Hardware subscriptions should not be necessary for basic play.

## Offer ladder

Core six-player kit; accessory straps/replacement pods; larger group expansion; paid premium game packs only after a strong free library; event/corporate bundle with facilitation tools; rental for trial and hospitality.

MANUAL 19

# Business Model Manual

## Primary model

Sell a reusable hardware kit with an included permanent game library. Grow lifetime value through optional expansion pods, accessories, new premium games, gifting, events, and replacement/service—not by disabling core functionality behind a subscription.

## Customer segments

UAE families/friends; gift buyers; party/event organizers; hospitality venues; youth/community groups after safety validation; later corporate team-building providers and regional distributors.

## Channels

Direct online pre-orders, pop-up demonstrations, partnerships with event organizers, curated gift retailers, corporate pilots, and rentals. The product needs live demonstration because the value is experiential.

## Unit-economics worksheet

Revenue minus landed COGS, payment fees, fulfilment, warranty/returns, customer support, and variable content/service cost equals contribution margin. Compare contribution margin against blended customer acquisition cost and return/refund rate.

## Defensibility

Reliable hardware/software integration, original tested game library, brand/community, proprietary event/game engine, industrial design, manufacturing know-how, and accumulated anonymous playtest insights. Game ideas alone are weak protection.

MANUAL 20

# Marketing Manual

## Core message

One compact kit changes what a gathering can become: active games, team challenges, reaction rounds, and low-mobility social missions using the same six devices.

## Proof content

Show setup in under five minutes; a clear 15-second gameplay loop; real reactions; multiple distinct games; offline play; safe play-space setup; kit reset and replay. Avoid implying association with any television show.

## Launch content plan

Founder build story; product reveal; how-it-works animation; three game demos; host tutorial; UAE villa/ghabga use case; reliability test; playtester reactions; pricing/pre-order; delivery/support updates.

## Demonstration funnel

Short video -> landing page -> email/waitlist -> small paid or deposit-backed playtest -> pre-order. Measure click-through, qualified signup, demo attendance, deposit conversion, acquisition cost, and refund intent.

## Community loop

Invite owners to vote on new mechanics, publish seasonal game updates, run host challenges, and reward useful playtest reports. Moderate for safety and never collect children's content without a dedicated compliant process.

MANUAL 21

# Launch Strategy

Twelve-week roadmap from one-node proof through six-node bench test, wearable alpha, and paid pilot

Figure 4. Twelve-week path from technical proof to a paid evidence-gathering pilot.

## Stage 1 - proof (weeks 1-4)

One-node technical proof, six-node bench test, Pulse Hunt paper prototype, and ten customer interviews. Gate: reliable events and clear demand for active social play.

## Stage 2 - alpha (weeks 5-8)

Wearable housings, local host UI, Pulse Hunt plus Signal Chain and Echo Match, five supervised groups. Gate: repeat play, safe behavior, setup under five minutes.

## Stage 3 - paid pilot (weeks 9-12)

Ten kits or facilitated sessions, deposits/fees, support logs, willingness-to-pay, and supplier DFM review. Gate: no open critical defects and credible unit economics.

## Stage 4 - engineering validation

Custom PCB, DVT enclosure, battery/charger validation, pre-compliance testing, TDRA/MoIAT classification, privacy/legal documents, brand clearance, and pilot manufacturer.

## Stage 5 - controlled UAE launch

Limited inventory, local fulfilment, bilingual quick-start/safety material, responsive support, spare stock, and weekly defect/review meeting. Expand only after return, support, and reliability metrics stabilize.

## Stop conditions

Unsafe common behavior, persistent missed/duplicate hits, less than 50% desire to replay after iteration, setup consistently above ten minutes, supplier cost that destroys contribution margin, or regulatory path inconsistent with the model.

MANUAL 22

# UAE Business and Compliance

## Business setup

Select the exact activities first: e-commerce/trading of electronic games or toys, software/content, import, and possibly event services. Mainland setup steps include activity, legal form, trade licence, trade name, initial approval, premises, and additional approvals: https://u.ae/en/information-and-services/business/doing-business-on-the-mainland/steps-to-start-a-business-on-the-mainland

A free-zone company may face regulated access to mainland sales, so model the intended sales channel and distributor structure before choosing. Obtain professional UAE legal/accounting advice for the specific emirate and activities.

## Wireless and product conformity

Confirm TDRA equipment classification and supplier registration/type-approval requirements before commercial import or sale. Current policy covers entities involved in registration, approval, import, distribution, display, sale, and commercial use of telecommunications equipment. Start here: https://tdra.gov.ae/en/Services/service-card?sID=Cu4EDmeifjoQ1zAbgYV59qYlswfGAtcsK_IwGX8c0LQ

Confirm whether the kit, battery charger, and toy/electronic classification are regulated under MoIAT conformity programmes. A conformity application for regulated products requires a valid trade licence and accredited test report: https://moiat.gov.ae/en/services/issue-conformity-certificates-for-regulated-products

## Data protection

UAE Federal Decree-Law No. 45 of 2021 creates obligations for personal-data processing, security, consent/other lawful bases, rights, and cross-border transfers. Minimize data and keep MVP play local: https://u.ae/en/about-the-uae/digital-uae/data/data-protection-laws.

## Tax

As of this handbook date, UAE resident businesses must register for VAT when taxable supplies/imports exceed AED 375,000 in the prior 12 months or are expected to exceed it in the next 30 days; voluntary threshold is AED 187,500. Verify current rules and your facts: https://www.tax.gov.ae/en/services/vat.registration.aspx

## Practical compliance file

Trade licence/activities; customs/importer setup; TDRA correspondence and certificate; MoIAT classification/certificate; battery transport documents including UN 38.3; accredited safety/EMC/radio reports; supplier declarations; labels/manuals; risk assessment; privacy notice/terms; warranty/returns; incident/recall plan; serial/lot traceability.

## Important limitation

This manual is a planning checklist, not legal, tax, safety-certification, or regulatory advice. Confirm requirements with the relevant UAE authorities and qualified advisors before sale, import, claims, or children's use.

MANUAL 23

# Legal and IP Manual

## Originality boundary

Do not use the Running Man name, logos, visual identity, character/personality references, episode formats, signature props, promotional comparisons suggesting affiliation, or copied game presentations. Document independent development of names, rules, artwork, hardware, UI, and marketing.

## Protection stack

Trademark for final brand/product names and logos; copyright for software, artwork, manuals, sound, and written game expression; industrial design for distinctive product appearance; patent/utility analysis for genuinely novel technical inventions; contracts and confidentiality for supplier/source assets and unreleased designs.

UAE's Ministry of Economy and Tourism is the competent authority for trademarks, copyright registrations, patents, and industrial property. UAE guidance also notes that schemes, rules, or methods for playing games are not granted patents as such, while qualifying technical inventions may be evaluated separately: https://u.ae/en/information-and-services/business/intellectual-property

## Before naming or launch

Conduct UAE and relevant international trademark clearance; search company/trade names, domains, app stores, marketplaces, and social handles; document results; obtain professional advice on Nice classes likely covering games/toys, electronics, software, retail, and entertainment services.

## Contracts

Founder IP assignment; contractor work-made/assignment and confidentiality; firmware/software licences and open-source notices; manufacturer NDA, tooling ownership, quality/change controls, and no unauthorized production; playtester consent/release; retailer/distributor terms; privacy/website terms; warranty/returns.

## Claims discipline

Substantiate range, battery life, water resistance, age suitability, safety, durability, and number of included games. Do not claim certification before approval or use "patented" unless accurate for the jurisdiction/status.

MANUAL 24

# Future Expansion Roadmap

## Phase A - prove the platform

Six nodes, one hub, three excellent games, offline host UI, adult/older-teen supervised use, reliable event protocol, and repeat-play evidence.

## Phase B - consumer kit

Custom low-power PCB, certified battery/charging, robust enclosure and attachment, manufactured case, five-game library, bilingual content, updates, diagnostics, and UAE compliance.

## Phase C - library and accessories

Expansion pods to 8/12 players, floor/territory bases, wrist/vest attachments, spectator mode, seasonal game packs, creator tools with rule validation, and accessibility filters.

## Phase D - events and corporate

Multi-kit orchestration, facilitator dashboard, team analytics that avoid intrusive employee profiling, rental fleet management, quick sanitation/service, venue mode, and certified facilitators.

## Phase E - regional/global

Arabic/English localization quality, country-specific radio/product approvals, distributor/service strategy, regional cloud/data review, climate testing, and localized game research.

## Technology options to revisit

Lower-power Nordic radio architecture; charging contacts/case; secure OTA; larger mesh/multi-hub events; UWB only if precise ranging creates a proven game mechanic; motion sensors only after button simplicity is exhausted. Avoid feature creep that weakens reliability or setup.

## North-star metrics

Median setup under five minutes; session success >99%; repeat play within 30 days; games played per kit; support contacts per 100 sessions; return rate; contribution margin; safety incidents; and percentage of active owners using more than one game.

## Next seven actions

Buy the seven-board BOM; build the one-node proof; run a paper Pulse Hunt; implement acknowledged events; assemble six bench nodes; conduct the 1,000-press test; schedule the first supervised playtest and record the scorecard.

# Source register and limitations

Current regulatory and platform facts were checked against the official sources below on 19 August 2026. Component prices are planning estimates and must be replaced with live supplier quotations. This handbook is not legal, tax, medical, product-safety, or certification advice.

- Espressif ESP32-C3 overview: https://docs.espressif.com/projects/esp-hardware-design-guidelines/en/latest/esp32c3/product-overview.html
- Nordic nRF52840 product page: https://www.nordicsemi.com/products/nrf52840
- TDRA equipment approval service: https://tdra.gov.ae/en/Services/service-card?sID=Cu4EDmeifjoQ1zAbgYV59qYlswfGAtcsK_IwGX8c0LQ
- MoIAT conformity certificates: https://moiat.gov.ae/en/services/issue-conformity-certificates-for-regulated-products
- UAE mainland business steps: https://u.ae/en/information-and-services/business/doing-business-on-the-mainland/steps-to-start-a-business-on-the-mainland
- UAE data protection overview: https://u.ae/en/about-the-uae/digital-uae/data/data-protection-laws.
- UAE intellectual property: https://u.ae/en/information-and-services/business/intellectual-property
- Federal Tax Authority VAT registration: https://www.tax.gov.ae/en/services/vat.registration.aspx

PHYSICAL SOCIAL GAMES • BUILD HANDBOOK

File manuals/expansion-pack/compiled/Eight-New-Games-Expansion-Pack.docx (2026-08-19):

GAME LIBRARY • EXPANSION PACK 01

Eight New Games

Built for the Same Six Wearable Devices and Hub

Complete objectives, setup, rules, device behavior, winning conditions, variations, and safety notes

Concept image of six wearable game pods, one hub, and a carry case

One physical system. Eight additional styles of play.

Working game names - August 2026

# Expansion pack overview

These eight games are additional concepts. They do not repeat the first library's chase elimination, point theft, memory chain, guardian rescue, territory capture, pattern copy, background mission, or relay mechanics. Every concept uses the same six press-capable pods, RGB feedback, vibration, optional sound, and central hub described in the main business handbook.

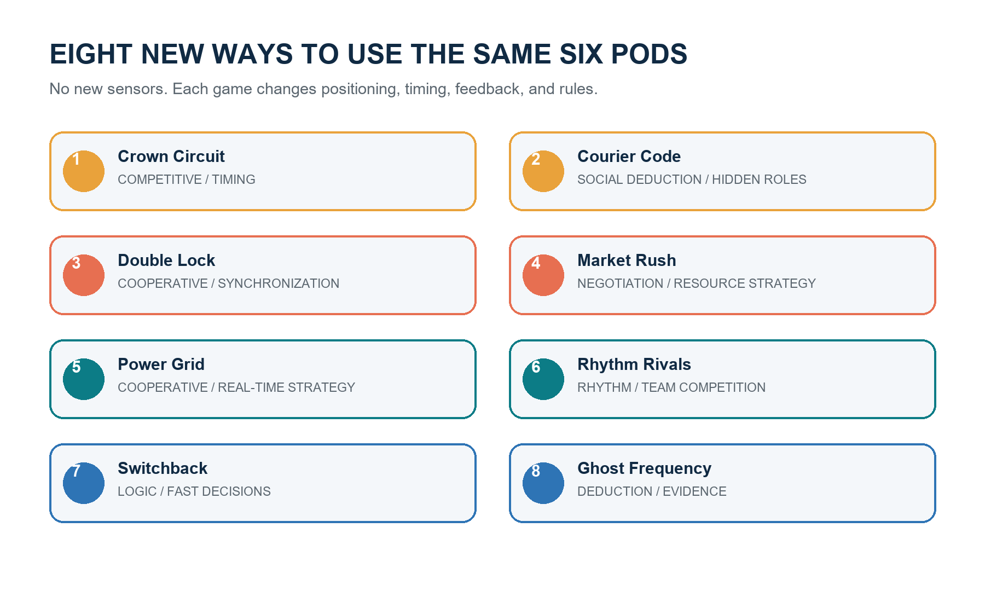
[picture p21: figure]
Map of eight new games and their primary mechanics

The hardware stays fixed; device placement and software rules create the variety.

## Hardware modes used

Mode | Use
Wearable/front clip | Players press another person's pod or their own safely.
Handheld | Private haptics, rhythm, voting, trading, and logic inputs.
Table/station | Pods become generators, locks, terminals, or fixed controls.
Hub screen | Public timer, state, clues, evidence, market, scoring, and winner.

## Library at a glance

Game | Primary mechanic | Players | Activity
Crown Circuit | Competitive | 4-6 | Medium
Courier Code | Social Deduction | 5-6 | Low
Double Lock | Cooperative | 3-6 | Low to medium
Market Rush | Negotiation | 4-6 | Low
Power Grid | Cooperative | 3-6 | Low to medium
Rhythm Rivals | Rhythm | 2-6 | Low
Switchback | Logic | 4-6 | Low
Ghost Frequency | Deduction | 4-6 | Low

## Universal safety rule

Applies to every game: touch only the device; never push, grab, tackle, restrain, block doors, or play near roads, stairs, pools, kitchens, vehicles, breakables, or other hazards. Stop for damaged hardware, heat, pain, unsafe behavior, or a loose attachment. The prototype remains supervised and 14+ until product safety and age suitability are formally validated.

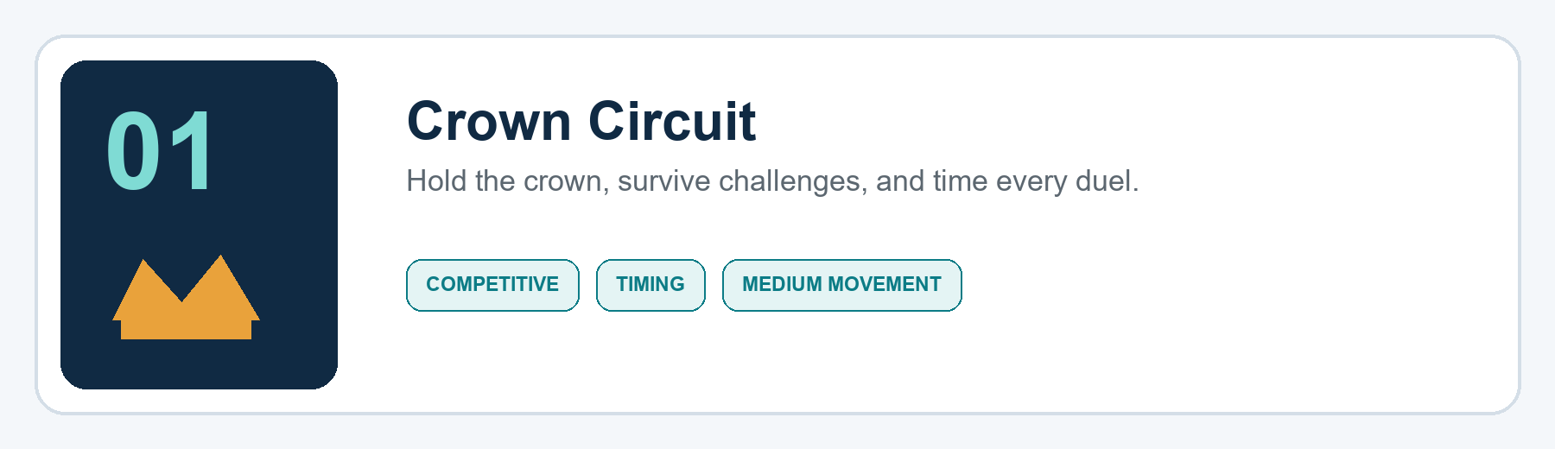
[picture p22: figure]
Illustrated title banner for game 1: Crown Circuit

Players | 4-6 | Duration | 8-12 minutes
Device position | Upper arm or front torso | Activity | Medium
Mode | Free-for-all | Best space | Clear room or garden

## Objective

Finish with the most Prestige by controlling the digital Crown, stealing it through clean device presses, and winning short reaction duels.

## Setup

1. Assign one pod to each player and attach it where the player can safely press their own pod during a duel.
2. Clear the play boundary and forbid stairs, roads, pools, door blocking, pushing, grabbing, and contact anywhere except the device.
3. Choose an 8-, 10-, or 12-minute match and a target of 15 or 20 Prestige.
4. Run the reaction calibration: every player waits for their LED cue and presses once.
5. The hub randomly awards the first Crown; that pod pulses amber while all others remain teal.

## How the pods and hub behave

- Amber pulse means Crown holder; teal means challenger; blue means duel pending; red means locked out.
- A challenger starts a duel by pressing the Crown holder's physical pod once.
- The two duelists step apart. After a random 1-3 second delay, both pods flash; the first valid self-press wins.
- A press before the cue is a false start. The hub timestamps both events and decides the result; nodes never decide locally.
- All other pods lock during the duel so outside presses cannot affect the result.

## Rules and round flow

1. The Crown holder earns one Prestige for every five full seconds of uninterrupted control.
2. A successful challenger gains two Prestige and receives the Crown.
3. A successful defense gives the Crown holder two Prestige.
4. After any duel, the winner receives a 10-second shield shown by a white LED ring; shielded players cannot be challenged.
5. A player may not challenge the same Crown holder twice in a row unless every other active player has attempted a challenge.
6. The round ends when the timer expires or a player reaches the target. Highest Prestige wins; longest total Crown time breaks a tie.

## Strategy and host guidance

The obvious move is to chase every opportunity, but timing matters more. Challengers should watch the shield and approach from a safe angle; the Crown holder can force impatient rivals into false starts. The rotation rule prevents two players from farming each other.

## Variations

- Team Circuit: two teams share Prestige; a Crown transfer within the team requires a two-second hold.
- Quiet Crown: use LED and vibration only for indoor gatherings.
- No-chase version: pods are placed on a table and players challenge only when the hub calls their name.

## Safety note

Host rule: Use walking or controlled movement in small rooms. Only the device may be touched. Pause immediately if the attachment loosens or players begin blocking, grabbing, or sprinting through unsafe areas.

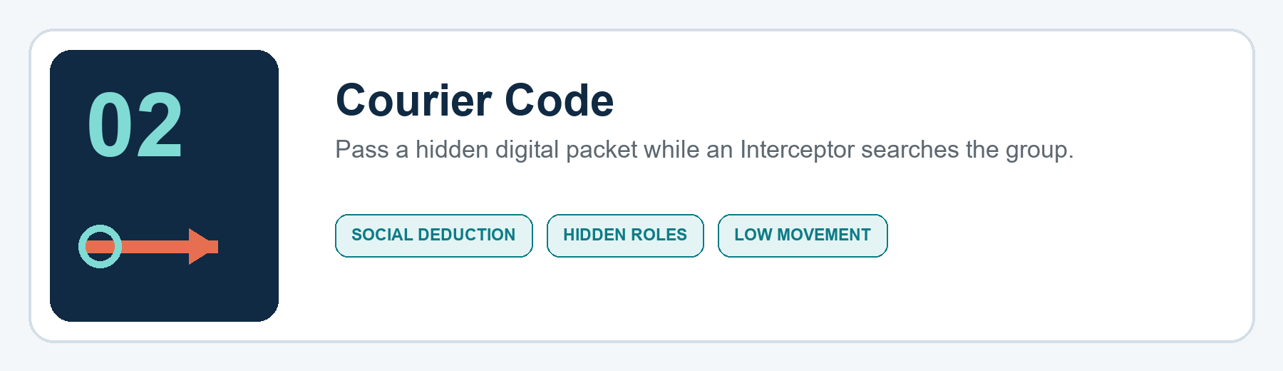
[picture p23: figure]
Illustrated title banner for game 2: Courier Code

Players | 5-6 | Duration | 10-15 minutes
Device position | Handheld or front clip | Activity | Low
Mode | Courier team vs Interceptor | Best space | Majlis, lounge, or table

## Objective

The Courier team must complete three secret packet handoffs and extract before time expires. The hidden Interceptor must identify and scan the current carrier.

## Setup

1. Give every player a pod, then ask players to close their eyes or look away from the host screen.
2. The hub privately assigns one starting Courier with a long vibration, one Interceptor with two short vibrations, and all other players as Agents with one short vibration.
3. Set a 12-minute round, three required handoffs, and three Interceptor scan tokens.
4. Enable private feedback: gameplay role and packet cues use vibration; LEDs remain neutral until a scan or final result.

## How the pods and hub behave

- The current carrier feels a soft heartbeat vibration every 20 seconds; nobody else receives it.
- To attempt a handoff, the carrier holds the recipient's pod for 1.5 seconds. The recipient must press their own pod within 2.5 seconds.
- A valid handoff transfers the packet and privately vibrates both pods. A decoy attempt produces no confirmation, allowing Agents to bluff.
- The Interceptor scans by double-pressing a target's pod within one second. The hub spends one scan token and reports hit or miss.
- The host screen shows time, number of completed handoffs, and scans remaining, but never shows the carrier.

## Rules and round flow

1. Players may talk, accuse, bluff, and perform decoy handoff gestures, but may not hide or cover another player's pod.
2. A carrier cannot hand the packet back to the player who gave it to them.
3. After each real handoff, the new carrier has a 12-second scan shield so the transfer cannot be punished instantly.
4. After three real handoffs, the carrier may extract by holding their own pod for three seconds during the final two minutes.
5. A correct scan ends the game for the Interceptor. An incorrect scan consumes one token and publicly marks the scanned player clear for 30 seconds.
6. If all scan tokens are used, the Interceptor may still win by correctly naming the carrier in one final host-screen accusation.

## Strategy and host guidance

Real and fake handoffs should look alike. The Courier team benefits from several believable decoys, while the Interceptor should track who avoids risk, who suddenly changes behavior, and which handoffs happen near shield timing.

## Variations

- Open Interceptor: reveal the Interceptor for a lighter family version.
- Two packets: for six experienced players, run two carriers and require both to extract.
- Silent round: discussion is allowed only during two 45-second briefing windows.

## Safety note

Host rule: This is a low-movement game. Handoffs are gentle presses on the device only; no searching clothing, restraining hands, or forcing a player to reveal private feedback.

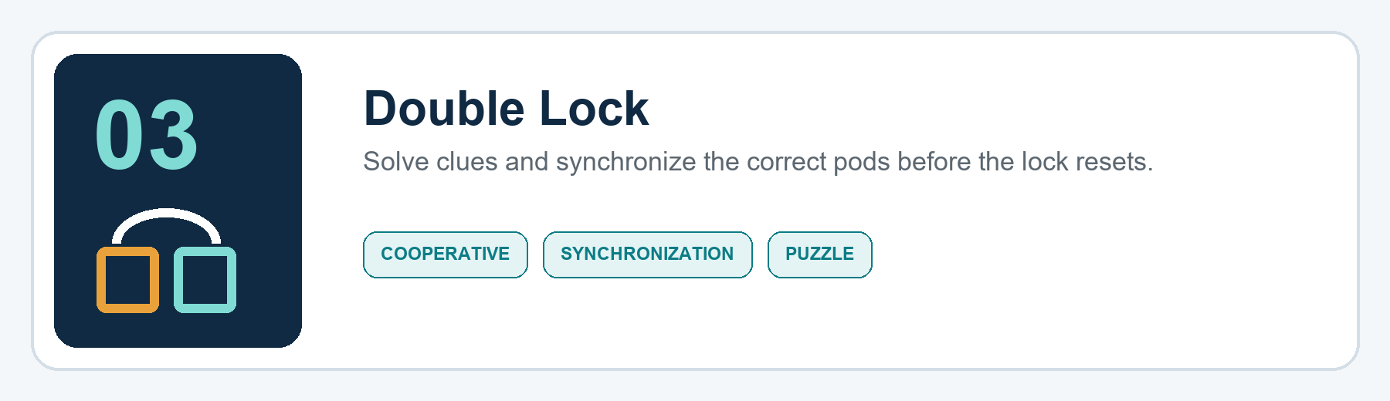
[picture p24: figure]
Illustrated title banner for game 3: Double Lock

Players | 3-6 | Duration | 8-12 minutes
Device position | Table or safe stations | Activity | Low to medium
Mode | Cooperative | Best space | Table, room, or garden stations

## Objective

Open six digital locks by interpreting clues and holding the correct pair or trio of pods at the same time before the countdown reaches zero.

## Setup

1. Place all six pods where they are easy to reach and label their colors on the host screen.
2. Choose Table mode for low movement or Station mode for a larger safe area.
3. Select six locks, a 10-minute master timer, and either two or three allowed mistakes per lock.
4. Run a synchronization test: two named players hold their pods together for two seconds.

## How the pods and hub behave

- The hub presents a clue such as 'the two colors that make green,' 'the neighbors of amber,' or 'the pair that flashed before blue.'
- Candidate pods glow dimly. Players may inspect and discuss without pressing.
- A lock attempt begins when one candidate is held; the matching pod must be held within 400 ms.
- Both holds must remain active for two seconds. LEDs fill toward the center to show synchronization progress.
- Correct combinations turn green and vibrate once. Incorrect combinations flash red, add a strike, and reset after three seconds.

## Rules and round flow

1. The team receives one clue at a time and may make only one active attempt at once.
2. Players may not move a pod after the first lock begins unless the host pauses the game.
3. Locks 1-2 use direct clues; locks 3-4 use memory; lock 5 adds a false candidate; lock 6 requires three synchronized pods.
4. Three strikes on one lock trigger a 20-second penalty and reveal a stronger clue.
5. The team wins by opening all six locks before the master timer expires.

## Strategy and host guidance

Assign one player to read, one to track earlier flashes, and one to count the synchronized hold. In Station mode, agree who covers each area before the clue appears so players do not collide.

## Variations

- Family clues: colors, simple sums, and visible sequences.
- Expert clues: negative clues, remembered order, and timed three-pod holds.
- Two-team race: each team controls three pods and must coordinate cross-team pairs for neutral locks.

## Safety note

Host rule: Station mode must use a clear one-way movement plan and non-slip surfaces. Place pods away from furniture edges, stairs, water, food preparation, and traffic.

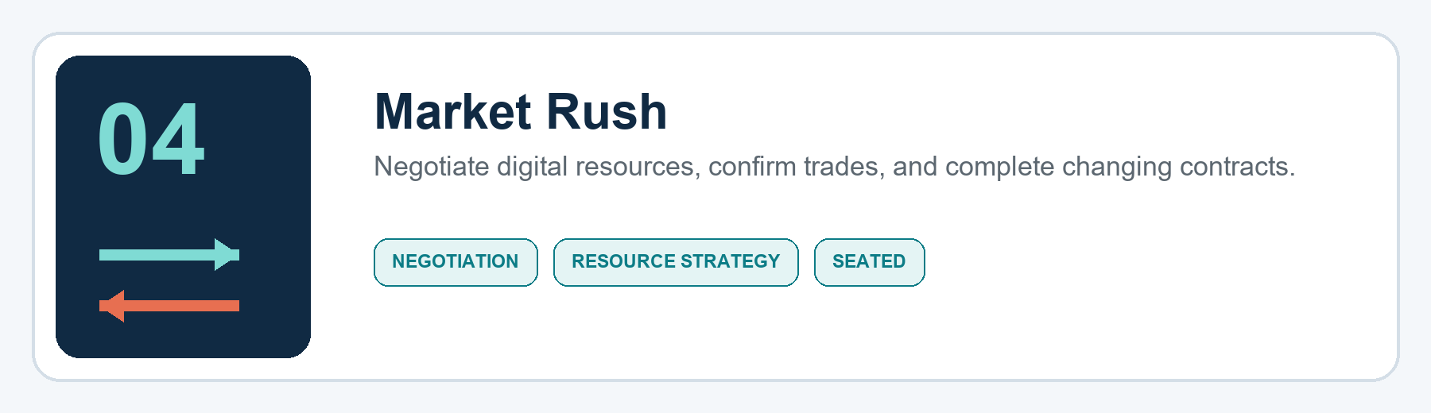
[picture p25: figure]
Illustrated title banner for game 4: Market Rush

Players | 4-6 | Duration | 15-20 minutes
Device position | Handheld or table | Activity | Low
Mode | Competitive negotiation | Best space | Table or majlis

## Objective

Earn the most Reputation by trading three fictional resources - Spark, Fabric, and Time - and completing public contracts before the market changes.

## Setup

1. Assign one pod per player and place the shared market dashboard where everyone can see it.
2. The hub gives each player five random resource units and displays three public contracts.
3. Choose four 90-second trading rounds plus 20-second settlement windows.
4. Run one practice trade so everyone understands select, confirm, and cancel.

## How the pods and hub behave

- Tap another player's pod once to open a trade between those two players on the host screen.
- Each player short-presses their own pod to cycle the resource they will give; double-press changes quantity between one and two.
- A long hold locks that side of the offer. When both players are locked, both pods pulse white.
- Both players press once within three seconds to execute. Either player may hold for two seconds to cancel before execution.
- A player completes an affordable public contract by holding their own pod during the settlement window; the hub spends resources automatically.

## Rules and round flow

1. Players may promise future trades, but only hub-confirmed exchanges are binding.
2. Only one trade per player may be open at a time; other invitations queue for five seconds and then expire.
3. Each contract awards Reputation and is replaced immediately after completion.
4. At the end of every trading round, a market event changes one resource bonus or contract type.
5. Unspent resources are worth little at the end, so hoarding is rarely optimal.
6. After four rounds, highest Reputation wins; completed contracts break ties.

## Strategy and host guidance

Information is public but urgency is not. Players can combine two modest trades into a high-value contract or create temporary alliances. The hub prevents accidental or impossible trades, so discussion remains the main skill.

## Variations

- Cooperative market: the group must complete ten contracts before four rounds end.
- Private holdings: show exact inventories only while a player presses and holds their pod near the screen.
- Fast market: 60-second rounds and single-unit trades only.

## Safety note

Host rule: All resources and Reputation are fictional game values. Do not connect the mechanic to money, betting, prizes based on chance, or real-world financial promises.

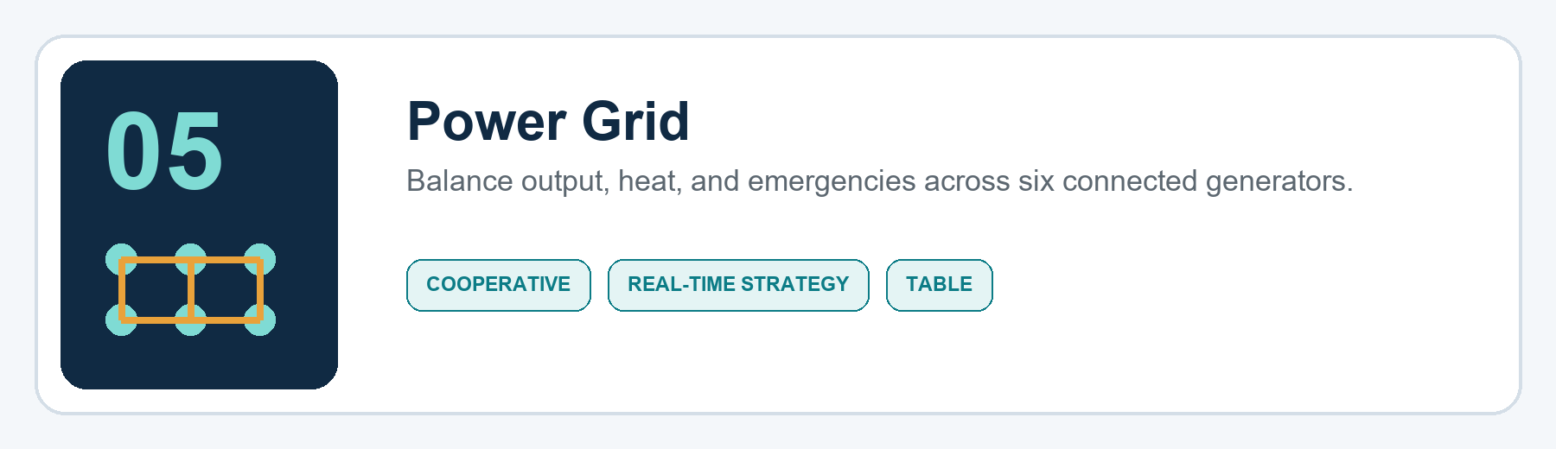
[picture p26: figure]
Illustrated title banner for game 5: Power Grid

Players | 3-6 | Duration | 8-12 minutes
Device position | Table or floor stations | Activity | Low to medium
Mode | Cooperative | Best space | Table or six safe stations

## Objective

Keep total power within the city's changing demand band while preventing any generator from overheating until the shift ends.

## Setup

1. Place all six pods in a visible ring and assign one or two generators to each player.
2. Select Easy, Standard, or Storm difficulty and an 8- or 10-minute shift.
3. The host screen displays city demand, current supply, stability, and upcoming forecast.
4. Practice raising output, cooling, and performing a linked repair.

## How the pods and hub behave

- LED brightness shows generator output from zero to three; color shifts from teal to amber to red as heat increases.
- A short press raises output one level. A long hold cools the generator but lowers output one level.
- A double press enables a five-second boost: extra output now, followed by extra heat.
- When a repair symbol appears, two specified pods must be held simultaneously for two seconds.
- An overheated generator locks for 10 seconds and produces no power.

## Rules and round flow

1. Demand changes every 12-25 seconds and is previewed by a short forecast unless a Storm event hides it.
2. Supply more than one unit above or below demand drains Stability; an exact match slowly restores it.
3. Generators gain heat while producing at level three and cool while at zero or during a long hold.
4. Crisis events include a maintenance pair, temporary generator outage, rapid demand spike, and controlled shutdown.
5. The team wins if time expires with Stability above zero. The team loses if Stability reaches zero or three generators overheat together.

## Strategy and host guidance

Use the forecast rather than chasing the current number. Keep one generator cool as reserve, announce every boost, and assign a player to watch Stability instead of a physical pod.

## Variations

- Young/family mode: slower demand changes and no hidden forecast.
- Blackout challenge: begin at zero and reach a stable target through a controlled sequence.
- Two-grid mode: teams manage three generators each but share one city Stability meter.

## Safety note

Host rule: In floor-station mode, players walk between fixed stations; do not run. Keep pods visible, stable, dry, and outside paths where they could be stepped on.

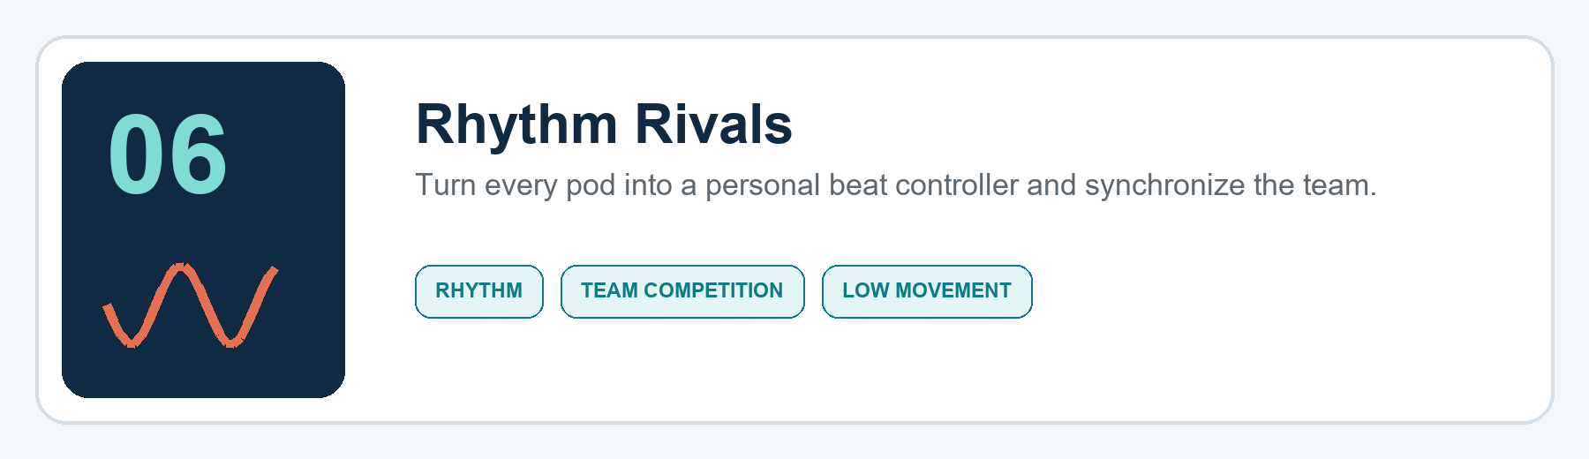
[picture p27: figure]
Illustrated title banner for game 6: Rhythm Rivals

Players | 2-6 | Duration | 6-10 minutes
Device position | Handheld or table | Activity | Low
Mode | Solo or two teams | Best space | Seated or standing circle

## Objective

Score accurate notes, complete team sequences, and finish with the highest Groove score using original click-and-percussion tracks from the hub.

## Setup

1. Place each pod in a player's hand or directly in front of them on a stable surface.
2. Run latency calibration: the hub flashes and clicks five times while players press on cue.
3. Choose Solo, Teams, or Cooperative; select tempo and a three-, five-, or seven-track set.
4. Set sound volume appropriate to the room or enable visual-and-vibration mode.

## How the pods and hub behave

- A pod glows one beat before its note. The player presses on the audio click or full-bright LED cue.
- Short presses play normal notes; holds sustain long notes; a double press triggers a marked accent.
- Team notes require two or three named pods within the timing window.
- The hub scores Perfect, Good, Late, Early, or Miss using calibrated event timestamps.
- A clean streak adds a gentle LED trail; misses use a brief neutral pulse rather than punitive noise.

## Rules and round flow

1. Only press when your pod cues unless the track shows an all-player unison symbol.
2. A player cannot gain extra points from repeated presses inside one note window.
3. Each track contains solo notes, relay notes that move around the group, and one team finish.
4. Team score combines timing accuracy and synchronization; one very early press can break a team note.
5. Highest Groove after the chosen set wins. Cooperative mode wins by reaching the target accuracy.

## Strategy and host guidance

Watch the pre-cue without anticipating the actual beat. In team mode, count aloud during practice, then rely on the track. Accurate simple notes are worth more than frantic extra presses.

## Variations

- Silent rhythm: vibration and LED only.
- Conductor: one player designs a short live sequence and the group repeats it.
- Ghabga round: slower call-and-response patterns with room for conversation between tracks.

## Safety note

Host rule: Keep volume comfortable and provide visual/vibration alternatives. Pods stay in hands or on the table; no striking furniture, bodies, or devices to create sound.

Illustrated title banner for game 7: Switchback

Players | 4-6 | Duration | 8-12 minutes
Device position | Handheld in a circle | Activity | Low
Mode | Competitive or cooperative | Best space | Table, majlis, or circle

## Objective

Keep the digital Signal moving to valid players while global Switchback rules reverse or modify short, long, and double presses.

## Setup

1. Seat or stand players in a clear circle and assign each a stable position number and pod color.
2. Teach the base controls: short press passes clockwise, long hold passes counter-clockwise, double press jumps one player.
3. Choose Cooperative survival or Competitive three-life mode.
4. Start at slow speed with one modifier; increase speed only after a clean practice round.

## How the pods and hub behave

- The active pod pulses white and vibrates once; that player has 2.5 seconds to act.
- The hub announces active modifiers on screen and with a unique sound/vibration pattern.
- Reverse swaps short and long directions. Mirror requires the next player to repeat the same gesture. Color Gate permits passing only to the displayed color group.
- Lockdown names a target; the group must route the Signal to that player within three moves.
- The hub rejects invalid destinations and records a Fault without moving the Signal.

## Rules and round flow

1. Only the active player may issue a route command.
2. A valid command moves the Signal immediately and resets the decision timer.
3. Every 20-35 seconds the hub adds, removes, or swaps one modifier; no more than two modifiers are active in Standard mode.
4. A timeout, invalid gesture, or impossible destination produces one Fault.
5. Competitive mode removes one life from the player who caused the Fault; at zero they remain in the circle as a pass-through position but cannot win.
6. Cooperative mode wins by surviving eight minutes with fewer than ten group Faults.

## Strategy and host guidance

Say the current rule aloud when it changes, but do not shout conflicting instructions at the active player. Plan one move ahead during Lockdown and remember that the shortest route may become invalid under Color Gate.

## Variations

- Calm mode: four-second decisions and one modifier at a time.
- Memory mode: the modifier disappears from the screen after five seconds.
- Team lanes: odd and even positions score separately while sharing the same Signal.

## Safety note

Host rule: Play seated or standing in place. The challenge is cognitive, so physical speed is unnecessary; do not throw, slap, or pass the hardware itself.

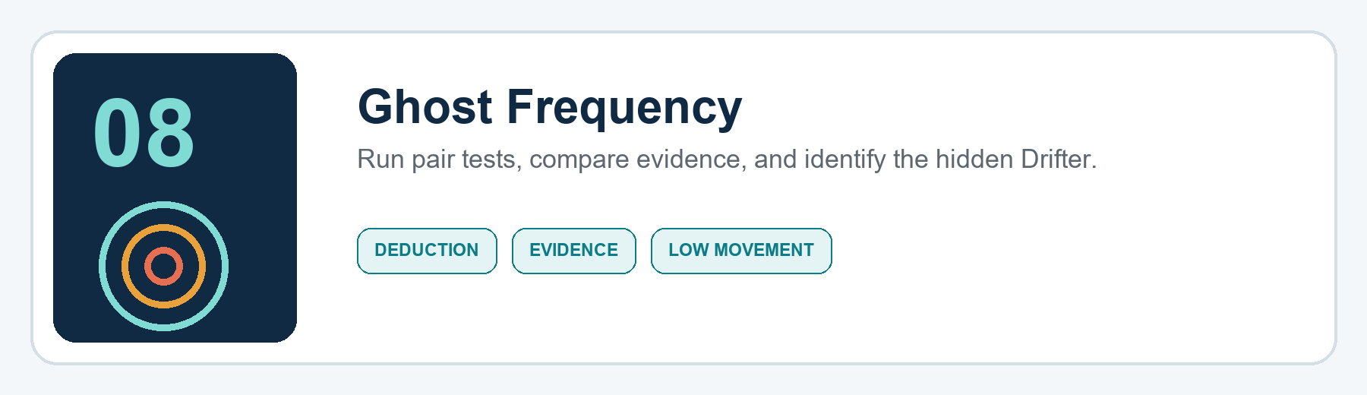
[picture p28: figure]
Illustrated title banner for game 8: Ghost Frequency

Players | 4-6 | Duration | 12-15 minutes
Device position | Handheld or table | Activity | Low
Mode | Group vs hidden Drifter | Best space | Table or discussion circle

## Objective

Operators must identify the hidden Drifter by running limited pair tests. The Drifter wins by surviving three investigation rounds and may corrupt one result.

## Setup

1. Assign every player a pod and ask players to look away while roles are delivered by vibration.
2. One player receives the Drifter pattern; all others receive the Operator pattern.
3. The hub secretly assigns each pod a frequency group while ensuring the evidence has one unique solution.
4. Give the group six pair tests across three investigation rounds and the Drifter one Interference charge.

## How the pods and hub behave

- A player opens a pair test by pressing another player's pod once; both players then hold their own pods for two seconds.
- The hub returns SAME or DIFFERENT through green/amber LED patterns and logs the result on the public evidence board.
- The Drifter may double-press during one of their tests to spend Interference and invert that result; the public log marks that one result in the game may be corrupted.
- During voting, each pod cycles through candidate colors with short presses. A long hold commits the vote and turns the LED off to hide the choice.
- The hub reveals all votes together after every active player has committed.

## Rules and round flow

1. Round one permits two tests, round two permits two, and round three permits the final two.
2. The same pair cannot be tested twice unless a special Recheck token is earned by a unanimous discussion vote.
3. Players may share reasoning, bluff, or accuse, but may not reveal the private role vibration by replaying or imitating it physically.
4. A majority accusation at the end of a round removes that player from testing but not from discussion.
5. Operators win immediately if the Drifter is removed. The Drifter wins after the third vote or if only two active players remain.
6. If the group finds a contradiction, they must decide which result was corrupted rather than assuming the system failed.

## Strategy and host guidance

Build a simple evidence graph: SAME links likely share a group; DIFFERENT links separate groups. The Drifter should corrupt a result that creates two plausible stories, not an obvious contradiction.

## Variations

- Open-data mode: no corruption charge; ideal for first-time players.
- Two Drifters: six experienced players, eight tests, and one shared Interference charge.
- Cooperative logic mode: no hidden role; identify which pod the hub intentionally configured differently.

## Safety note

Host rule: Keep the discussion playful. Ban personal insults, real-world accusations, exclusion outside the game, and pressure to reveal private information. The hidden role is fictional and ends with the round.

# Playtest and release checklist

A concept enters the sellable library only after its rules, software state, physical behavior, and recovery cases are tested. Use the same evidence standard for every game.

1. Run one paper or facilitator-led version before implementing software.
2. Test every short, long, double, simultaneous, early, late, duplicate, and disconnected input that the game uses.
3. Define what happens when a player or pod leaves during the round.
4. Measure explanation time, setup time, round length, downtime, false inputs, and requests for another round.
5. Record safety interventions and remove any rule that rewards unsafe contact or movement.
6. Confirm the game feels meaningfully different from the existing library.
7. Lock the rule version, game-engine schema, feedback patterns, and host instructions together.
8. Ship only after unfamiliar hosts can run it from the guide without developer help.

## Recommended implementation order

Start with the least firmware risk and increase complexity gradually:

1. Double Lock - validates simultaneous holds and station mode.
2. Switchback - validates short, long, and double gesture routing.
3. Power Grid - validates continuous state and timed events.
4. Rhythm Rivals - validates calibrated timing and group synchronization.
5. Crown Circuit - validates duel locking and high-tempo acknowledgements.
6. Market Rush - validates transactional UI and two-party confirmation.
7. Courier Code - validates hidden roles and private haptics.
8. Ghost Frequency - validates evidence generation, secret voting, and rule-consistent deception.

EXPANSION PACK 01

Eight more reasons to replay the same box.

Six adults playing safely with wearable game pods in a cleared villa garden

One six-pod kit. Eight distinct new social experiences. No extra hardware.

Build first: Double Lock → Switchback → Power Grid

PHYSICAL SOCIAL GAMES | EXPANSION PACK

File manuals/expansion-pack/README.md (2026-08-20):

# Eight-Game Expansion Pack

Compiled versions:

- [PDF](compiled/Eight-New-Games-Expansion-Pack.pdf)
- [Word document](compiled/Eight-New-Games-Expansion-Pack.docx)

The illustrations used in this pack are stored in [`assets/expansion-pack`](../../assets/expansion-pack/).

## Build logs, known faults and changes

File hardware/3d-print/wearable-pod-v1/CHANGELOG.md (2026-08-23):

# Changelog

## V1 — 2026-08-23

- Created a 62 mm parametric wearable enclosure.
- Selected four heat-set inserts and screws for repeatable service access.
- Added tongue-and-groove alignment and a TPU compression gasket.
- Added a captured cap, TPU button diaphragm, and translucent light ring.
- Added a removable side-by-side battery/XIAO electronics carrier.
- Added independent USB-C and recessed power-switch openings.
- Added a replaceable strap plate, TPU drop bumper, and printer-tolerance coupon.
- Exported and validated watertight STL files plus an exploded GLB/PNG preview.

## Required physical-test feedback for V2

- Actual battery, connector, antenna, switch, LED, motor, and buzzer dimensions.
- Printer/material shrink and insert-hole selection from the coupon.
- Measured button force, travel, edge-press consistency, and false activation.
- Worn radio performance and best antenna position.
- Strap comfort, abnormal-load release, and clip/strap preference.
- Drop, sweat-wipe, heat, repeated opening, and charging-test results.
